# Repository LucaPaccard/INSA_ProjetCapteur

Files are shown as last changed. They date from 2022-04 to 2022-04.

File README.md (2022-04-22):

# 2021-2022_Paccard_Lemaire_Projet_Capteur
Ce projet s'inscrit dans l'UF **"Du capteur au banc de test"** en 4ème année au département de Génie Physique de l'INSA Toulouse.
***
L'objectif de ce dernier est d'élaborer un **capteur de déformation** low-tech à base de graphite. L'application d'une contrainte mécanique sur un capteur en papier sur lequel un dépôt de crayon à papier à été fait, modifie la distance entre les particules de graphite. La conductivité électrique de la couche de graphite est elle aussi modifiée et celà induit une variation de la résistance. C'est cette donnée qui va nous intéresser.

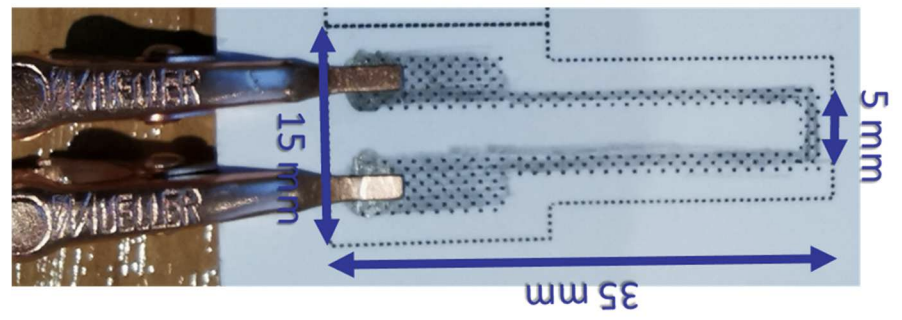
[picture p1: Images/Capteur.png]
<p align="center">

L'ensemble des étapes menées pour réaliser ce capteur, en allant du **design** jusqu'à la **réalisation** en passant par le **codage** seront détaillées dans ce dossier.

## Sommaire
* [1. Description du projet et détail des livrables](#PremiereSection)
* [2. Matériel nécessaire](#DeuxiemeSection)
* [3. Arduino](#TroisiemeSection)
  * [3.1. Librairies utilisées](#TroisiemeSection1)
  * [3.2. Code Arduino](#TroisiemeSection1)
* [4. Application Android](#QuatriemeSection)
* [5. KiCad](#CinquiemeSection)
  * [5.1. Symboles et empreintes des composants](#CinquiemeSection1)
  * [5.2. Schématique](#CinquiemeSection2)
  * [5.3. Placement des composants](#CinquiemeSection3)
  * [5.4. Visualisation 3D](#CinquiemeSection4)
* [6. Fabrication du shield](#SixiemeSection)
  * [6.1. Réalisation du PCB](#SixiemeSection1)
  * [6.2. Perçage et soudure](#SixiemeSection2)
* [7. Simulation](#SeptiemeSection)
* [8. Tests et résultats](#HuigtiemeSection)
  * [8.1. Banc de test](#HuigtiemeSection1)
  * [8.2. Résultats obtenus](#HuigtiemeSection2)
  * [8.3. Analyse des résultats et pistes d'améliorations](#HuigtiemeSection3)
* [9. Datasheet](#NeuviemeSection)
* [Contacts](#DixiemeSection)

## 1. Détail des livrables et description du projet 
Voici l'ensemble des livrables du projet :
- Un **shield PCB** se connectant à une carte **Arduino UNO** contenant un amplificateur transimpédance, un module bluetooth, un écran OLED et un encodeur rotatoire
- Un **code Arduino** permettant de mesurer la déformation du capteur et de piloter le module bluetooth, l'écran OLED et l'encodeur rotatoire
- Une **application Android APK**
- Un **protocole de test** 
- La **datasheet** du capteur de déformation

Tout d'abord, nous avons réalisé un code Arduino permettant de vérifier notre montage contenant un amplificateur transimpédance, un écran OLED, un module bluetooth et un encodeur rotatoire. Une fois le montage fonctionnel, nous avons réalisé le design de notre shield sur le logiciel *KiCad*. Nous l'avons ensuite fabriqué et assemblé (lithographie, perçage, soudage des composants, etc.). En parallèle de cela, nous avons utilisé le logiciel *MIT App Inventor* afin de développer une application Android APK, capable de communiquer et recevoir les informations envoyées par le module bluetooth telles que les valeurs de résistance du capteur mesurées. Nous avons par la suite mis en place un banc de test pour pour caractériser les différents types de capteurs en fonction de leur déformation et de la mine de crayon utilisée (HB, B, 9B, etc.). Enfin, nous avons établi une datasheet à l'aide des résulats obtenus par le banc de test.

## 2. Matériel nécessaire
Pour réaliser le capteur ainsi que le PCB associé, voici la liste des composants nécessaires :
* x2 résistance 100kΩ
* x1 résistance 10kΩ
* x2 résistance 1kΩ
* x1 capacité 1μF
* x3 capacité 100nF
* x1 amplificateur opérationnel LTC1050
* x1 module Bluetooth HC05
* x1 encodeur rotatoire KY_040
* x1 écran OLED I2C 0.91

## 3. Arduino 
### 3.1. Librairies utilisées 
Nous avons utilisé différentes librairies dans notre code Arduino. La librarie ["Adafruit_SSD1306"](/Libraries/Adafruit_SSD1306) permet de contrôller l'écran OLED. La librairie ["Adafruit_BusIO"](/Libraries/Adafruit_busIO) permet de gérer la connexion en I2C et SPI.

### 3.2. Code Arduino 
[Deux codes Arduino](https://github.com/MOSH-Insa-Toulouse/2021-2022_Paccard_Lemaire_Projet_Capteur/tree/main/Arduino) ont été développés sous Arduino IDE pour profiter au mieux des fonctionnalités de notre capteur.

#### Code Graphite_sensor
Le [premier code](https://github.com/MOSH-Insa-Toulouse/2021-2022_Paccard_Lemaire_Projet_Capteur/blob/main/Arduino/Graphite_sensor/Graphite_sensor.ino) permet d'assurer la communication entre la carte Arduino, qui récupère la valeur de tension renvoyée par le capteur, et les différents éléments ajoutés sur le shield soit : l'écran OLED, le module bluetooth et l'encodeur rotatoire. Différents menus sont accessibles sur l'écran OLED :
* Le premier menu permet un simple affichage de la résistance
* Le deuxième menu permet de selectionner le calibre de la résistance affichée sur le menu 1. Cette dernière peut ainsi être affichée en Ω, kΩ ou MΩ.
* Le troisème menu est un chronomètre permettant de savoir le temps d'execution du programme. C'est à dire le temps depuis le programme à été démarré.
* Le quatrième menu permet l'affichage d'une image.

En parallèle, le module bluetooth envoie les données de tension et de résistance à une application mobile qui sera détaillée dans la partie suivante.

#### Code Angle_calibration
Le [second code](https://github.com/MOSH-Insa-Toulouse/2021-2022_Paccard_Lemaire_Projet_Capteur/blob/main/Arduino/Angle_calibration/Angle_calibration.ino) Arduino permet d'effectuer un calcul d'angle par rapport à la calibration du capteur. L'utilisateur rentre les valeurs de la résistance à plat et à la position la plus courbée possible en appuyant sur le bouton poussoir présent sur l'encodeur rotatoire. En considérant la variation de résistance linéaire, un produit en croix est ensuite fait pour asssocier une valeur de résistance à un angle de déformation.

## 4. Application Android 

Nous avons réalisé une [application Android](https://github.com/MOSH-Insa-Toulouse/2021-2022_Paccard_Lemaire_Projet_Capteur/tree/main/Application%20bluetooth) grâce au site *MIT App Inventor* afin d'instaurer une communication entre notre module bluetooth HC-05 et un smartphone Android. Cette application possède différentes fonctionnalités : après avoir choisi dans un menu l'appareil auquel on souhaite se connecter, et que la connexion a été effectuée, différentes informations sont affichées sur l'écran du téléphone. En premier, on trouve la tension VADC en volts de sortie du circuit, elle est envoyée sous forme d'un byte à l'application depuis la carte Arduino, puis elle est reconvertie dans le code de l'application en float permettant d'afficher les décimales. C'est ensuite la valeur de la résistance du capteur en graphite qui est affichée en Méga Ohms, la valeur est directement calculée depuis l'application à partir de la valeur de VADC reconvertie en float. Finalement, la variation de la valeur de résistance est tracée en fonction du temps dans un graphique (canva) au-dessous. Nous avons enregistré un graphique avec uniquement des axes et leurs titres sous forme d'image que nous avons ensuite mis en fond du graphique pour le tracé. 

## 5. KiCad 
### 5.1. Symboles et empreintes des composants 
* Amplificateur LTC1050

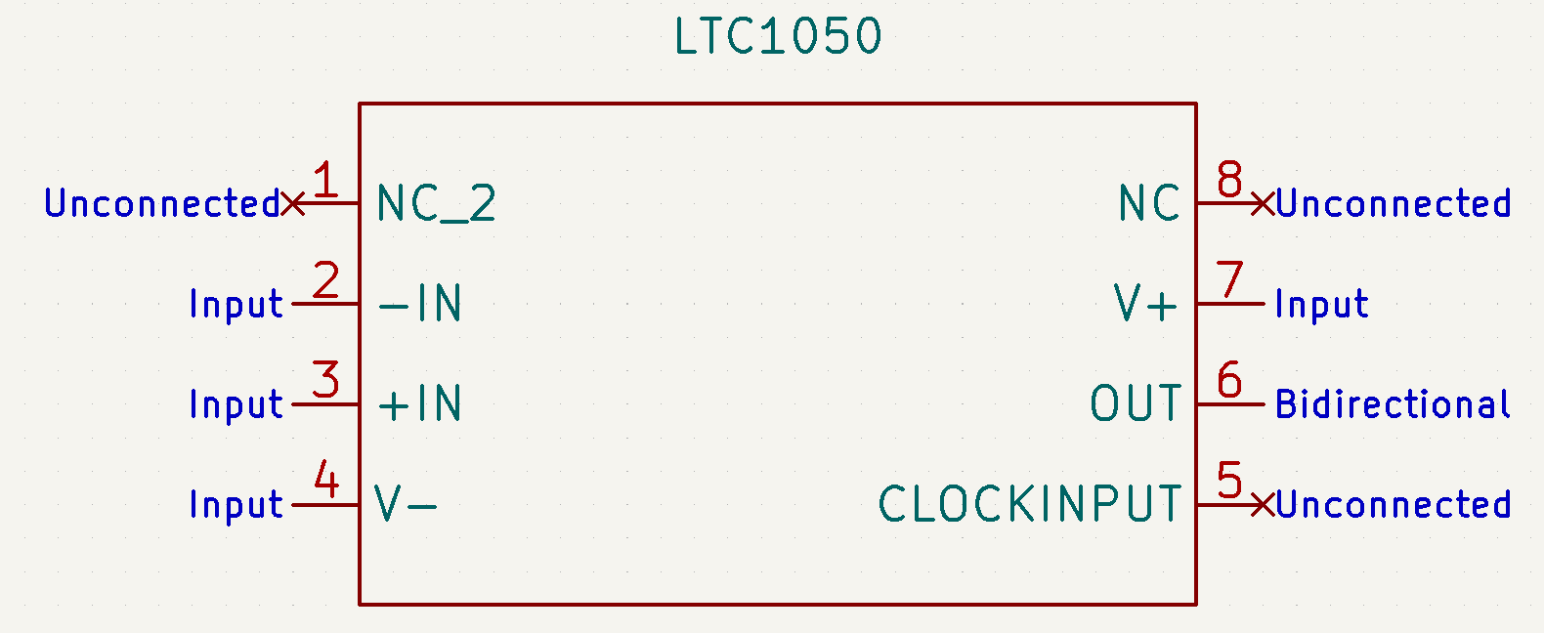
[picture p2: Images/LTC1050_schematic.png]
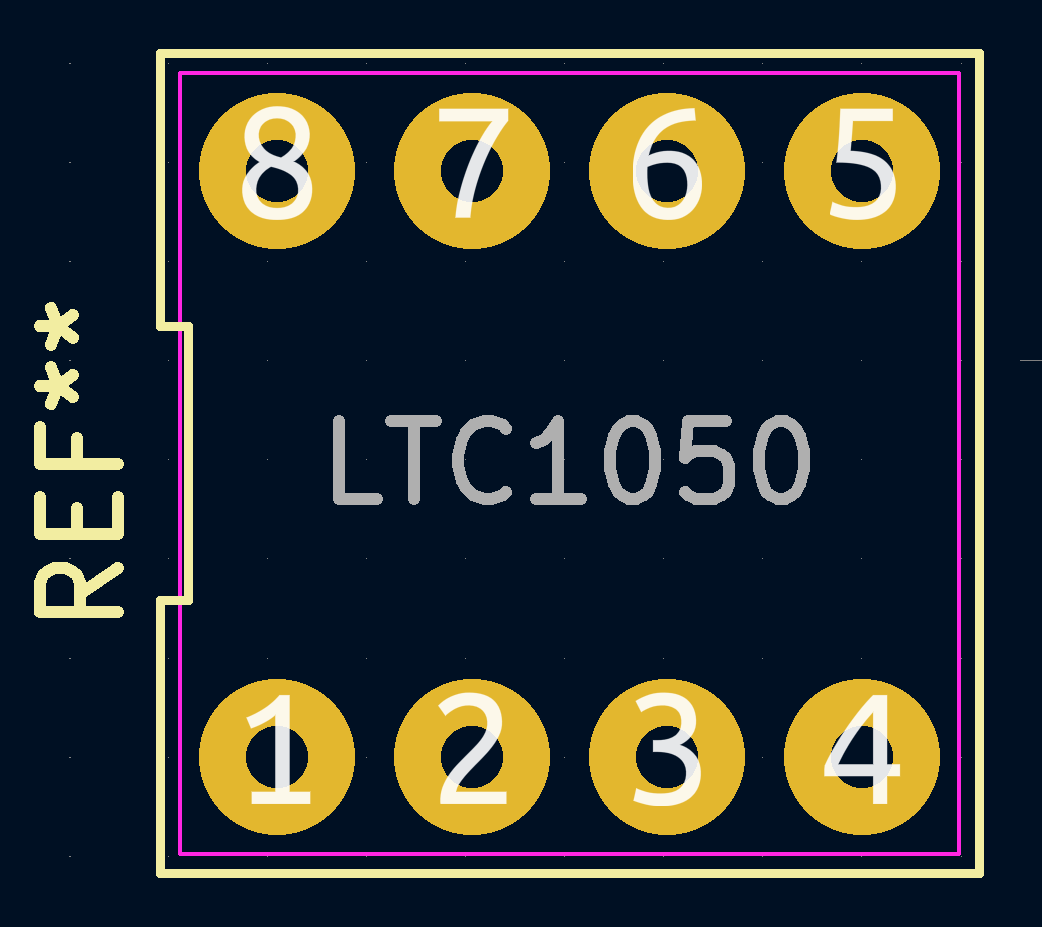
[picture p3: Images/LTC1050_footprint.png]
 

* Ecran OLED

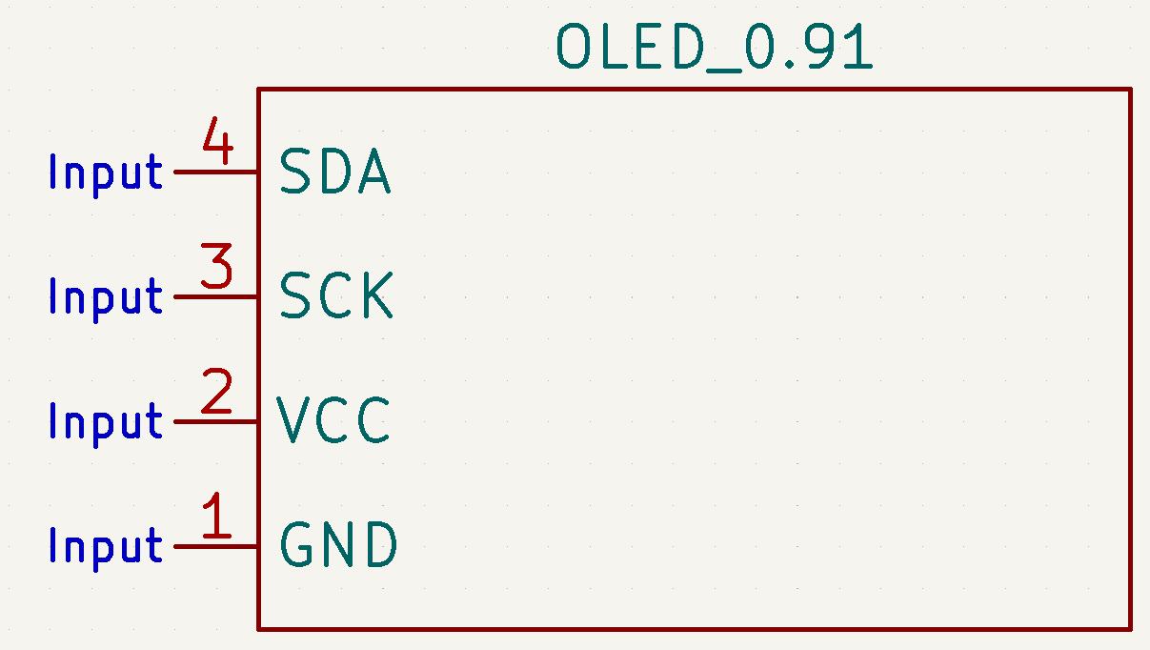
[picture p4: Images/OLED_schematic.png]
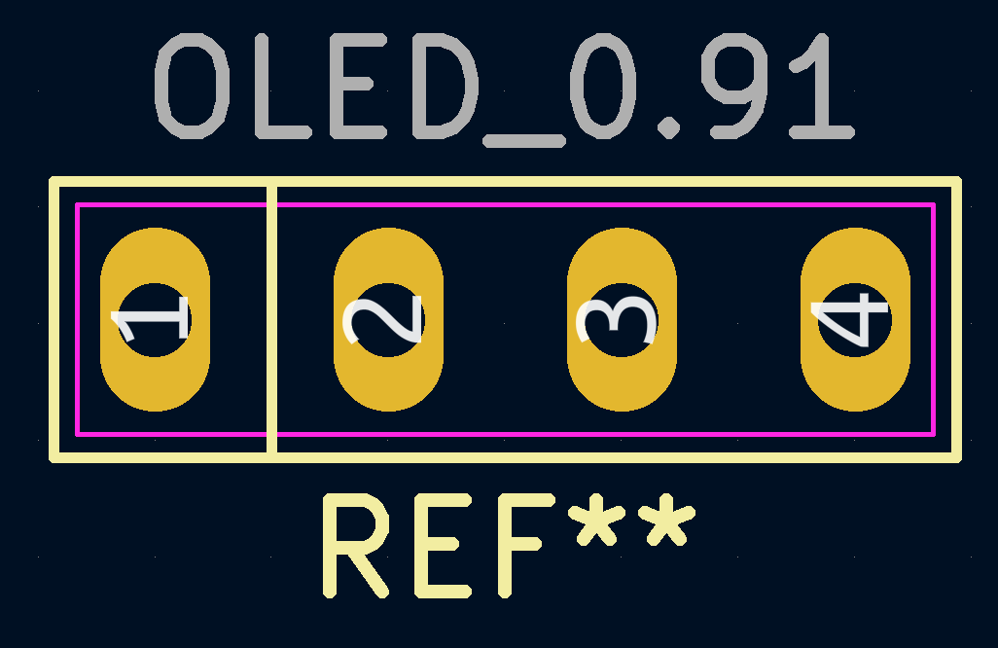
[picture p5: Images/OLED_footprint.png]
 

* Encodeur rotatoire KY_040

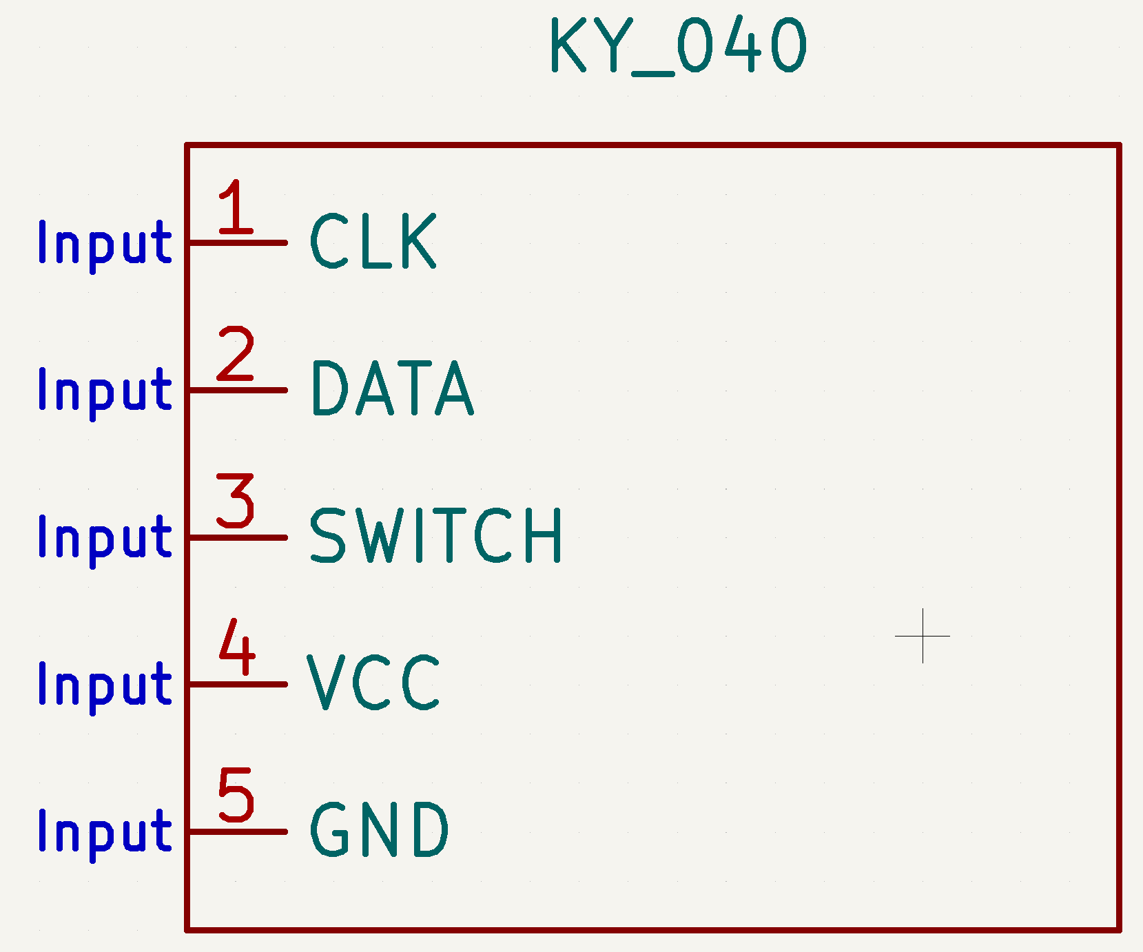
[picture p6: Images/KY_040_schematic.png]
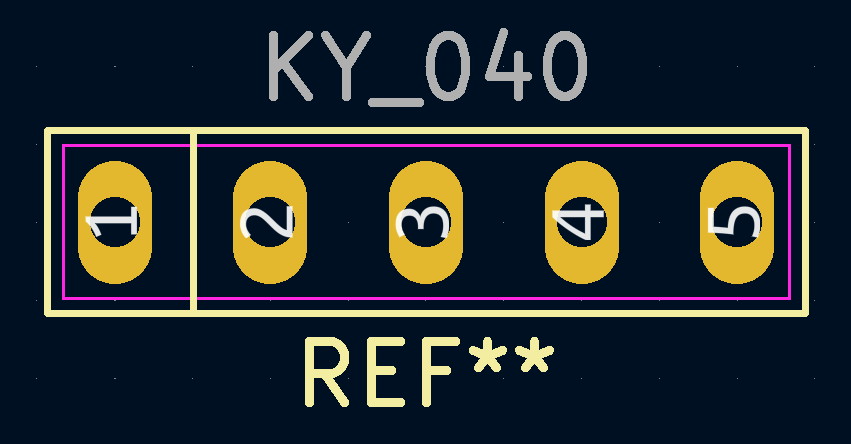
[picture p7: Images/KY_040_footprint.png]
 

* Module bluetooth HC05

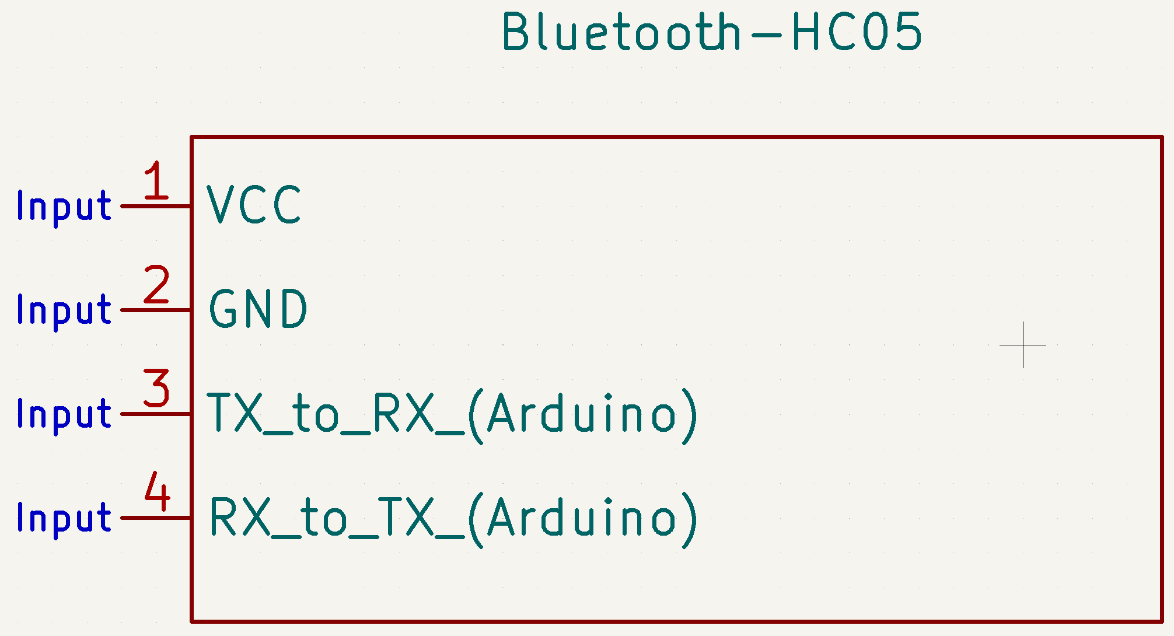
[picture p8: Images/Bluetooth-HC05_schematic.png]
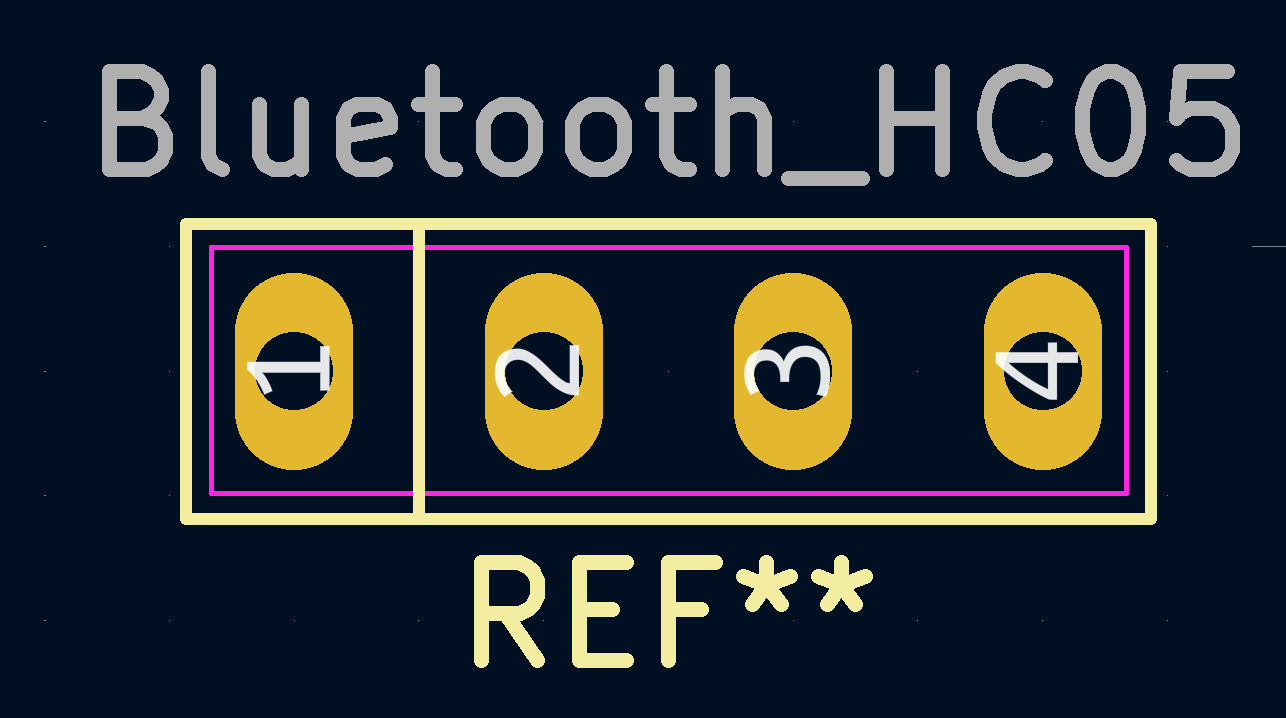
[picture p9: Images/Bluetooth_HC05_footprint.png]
 

### 5.2. Schématique 
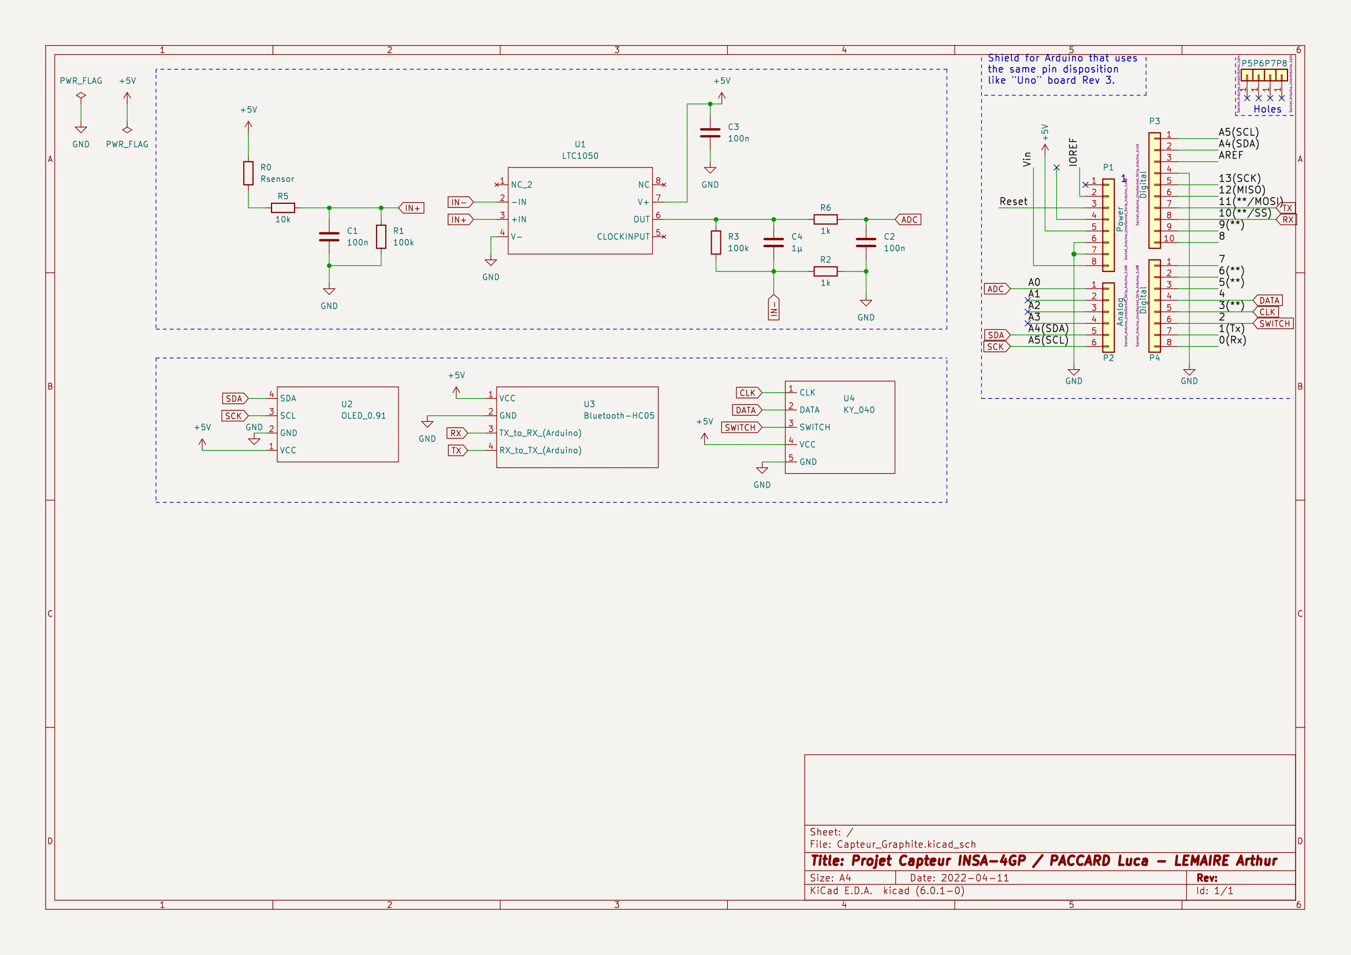
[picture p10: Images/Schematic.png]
<p align="center">

Une fois les empreintes créées, nous avons réalisé le schéma de notre shield. En haut à droite sont représentées les broches de la carte Arduino. En haut au milieu est représenté l'amplificateur transimpédance et en bas du schématique se trouvent l'écran OLED, le module bluetooth et l'encodeur rotatoire.

### 5.3. Placement des composants 
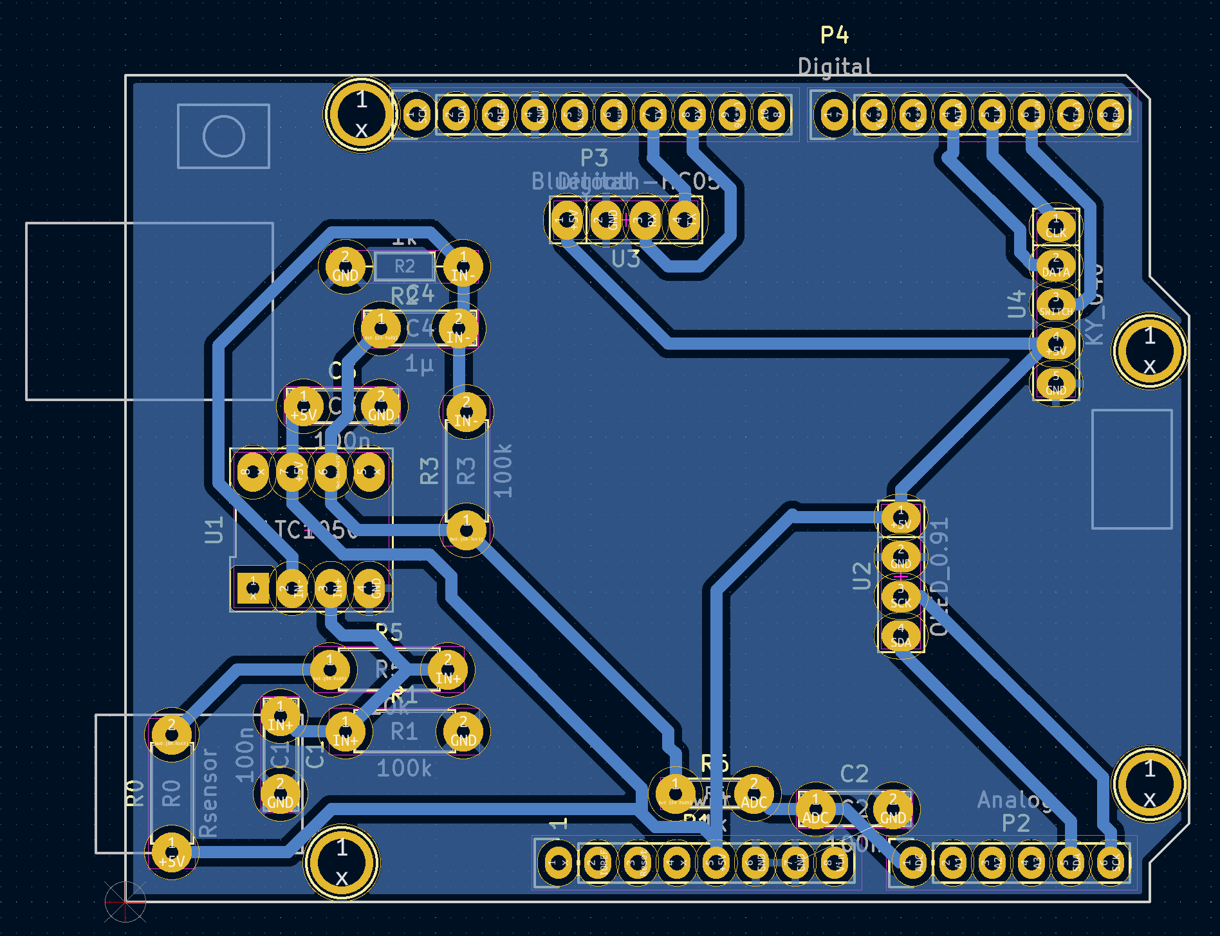
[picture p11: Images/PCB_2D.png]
<p align="center">

### 5.4. Visualisation 3D 
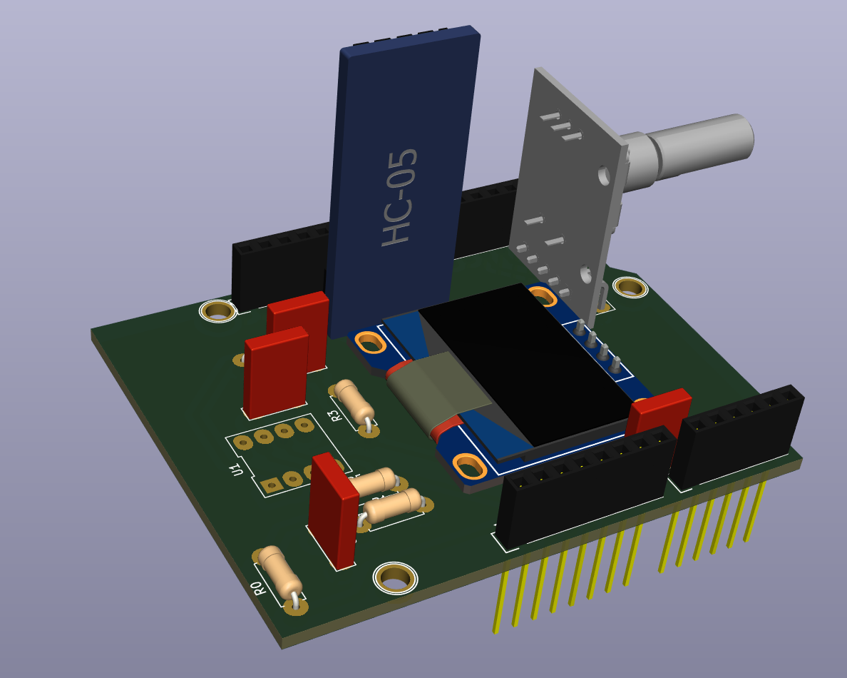
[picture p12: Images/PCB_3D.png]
<p align="center">

## 6. Fabrication du shield 
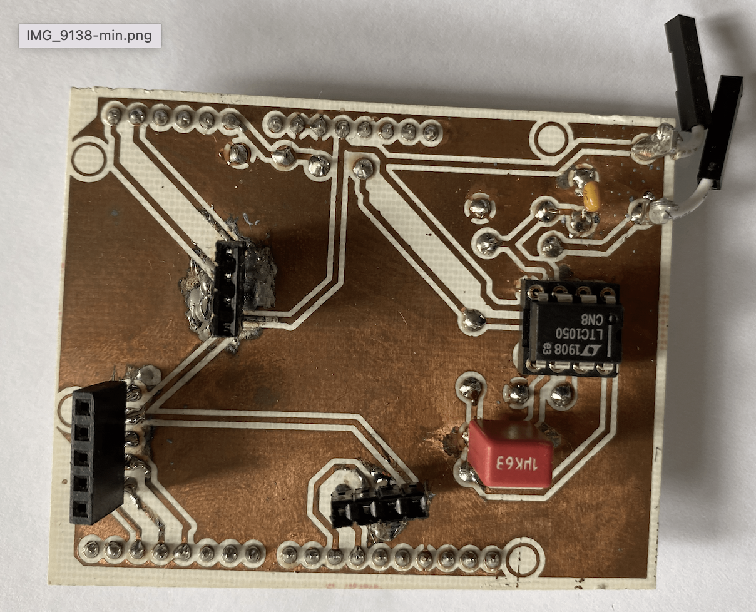
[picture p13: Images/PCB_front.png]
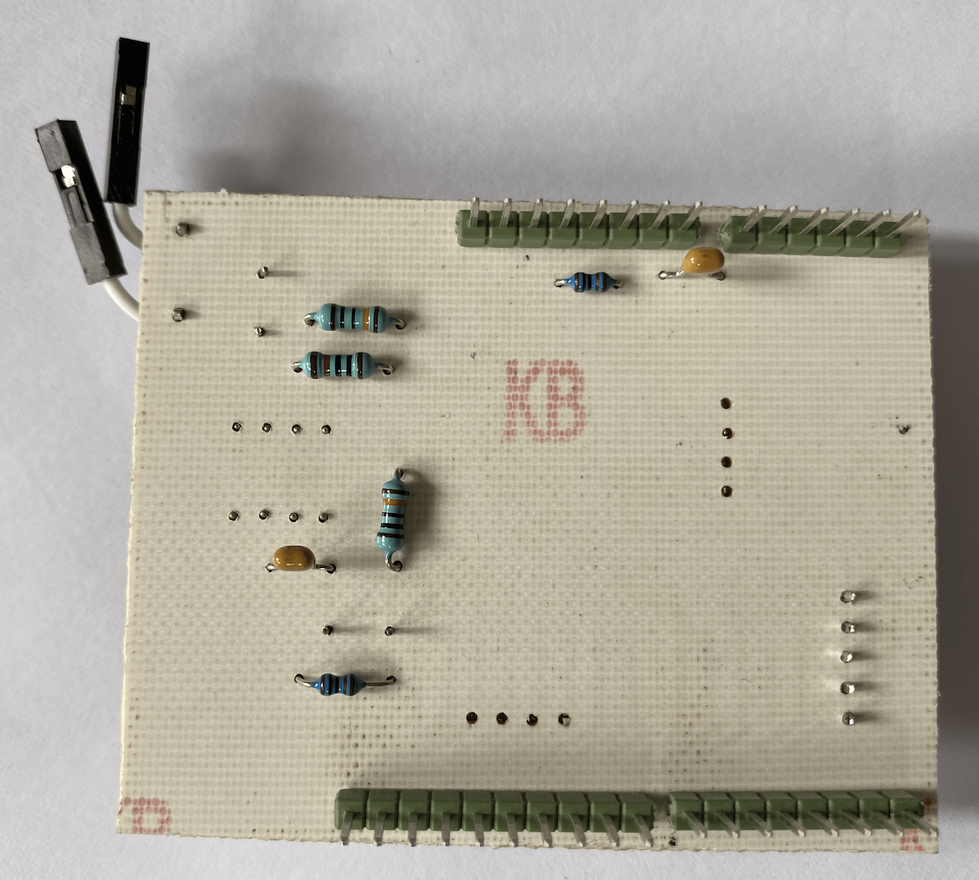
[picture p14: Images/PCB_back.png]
 

### 6.1. Réalisation du PCB  
Le PCB a été réalisé au sein des départements de Génie Physique (GP) et Génie Électrique et Informatique (GEI) de l'INSA Toulouse avec l'aide de Catherine Crouzet. Notre PCB à été fabriqué à partir d'une plaquette d'epoxy recouverte d'une fine couche de cuivre (environ 60μm). 
Nous avons imprimé sur du papier calque la modélisation de notre PCB effectuée sur le logiciel *KICAD* pour ensuite insoler aux UV notre plaquette avec la silouhette par-dessus pendant quelques minutes. À l'aide d'un révelateur, nous avons retiré la partie de la résine non insolée.
La plaquette d'expoxy est ensuite placée dans un bain de perchlorure de fer pour la gravure, opération durant 7 minutes. Le cuivre non protégé par la résine est ainsi retiré de la plaquette ce qui nous permet d'obtenir le PCB avec les pistes souhaitées.
Enfin, de l'acétone est appliquée sur la plaquette pour éliminer les dernières traces de résine.

### 6.2. Perçage et soudure  
Nous avons ensuite percé notre PCB aux endroits où les différents composants seront insérés à l'aide d'une perceuse électrique. Le diamètre des trous dépend des différents composants à placer :
* ⌀ 0.8mm : AOP LTC1050, résistances et capacités
* ⌀ 1.0mm : Broches de connexion de la carte Arduino Uno et headers des différents modules (OLED, bluetooth, encodeur rotatoire)
* ⌀ 1.2mm : Broches de connexion du capteur de déformation

Notre PCB ayant été imprimé en face avant, certains composants ont été placé en face avant et d'autres en face arrière pour faciliter la soudure et la connexion à la carte Arduino Uno.

## 7. Simulation  
Nous avons simulé notre amplificateur transimpédance sur le logiciel *LTSpice* afin de savoir le comportement que notre circuit aura une fois branché à de réelles valeurs de tension. Les différentes simulations réalisées sur le logiciel nous ont permis d'une part de vérifier le bon fonctionnement du circuit et de chacun des composants intégrés, et d'autre part de comprendre l'utilité de chacun. Le détail de la démarche suivie et des résultats obtenus est disponible dans le document [Simulation_LTspice](https://github.com/MOSH-Insa-Toulouse/2021-2022_Paccard_Lemaire_Projet_Capteur/blob/main/Simulation_LTspice.pdf).

## 8. Tests et résultats  
### 8.1. Banc de test  
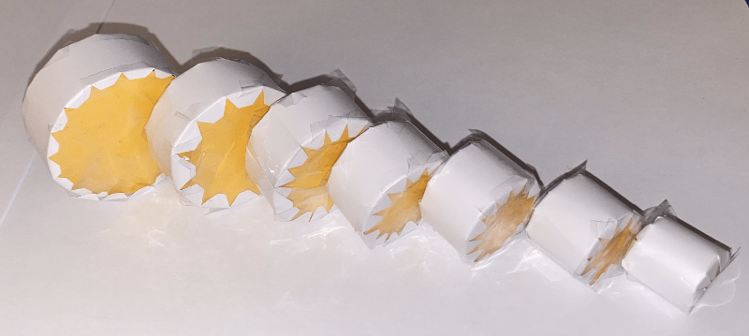
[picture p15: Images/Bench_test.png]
<p align="center">

Nous avons testé notre capteur sur un banc de test que nous avons conçu à partir de feuilles de papier épais. Nous avons fabriqué 7 cylindres de diamètre variable, allant de 5cm à 2cm par pas de 0,5cm.
En enrobant les différents cylindres avec notre capteur, nous appliquons une déformation maitrisée que nous pouvons calculer avec la formule : 
*ε = e / (2•R)*, avec ε la déformation, e l'épaisseur de notre capteur, et R le rayon de courbure appliqué soit le rayon de nos cylindres.

Nous avons décidé de réaliser des mesures de compression (graphite vers le cylindre) du capteur et pas en tension (graphite vers l'extérieur), car bien que ces deux méthodes soient possibles, les valeurs de  résistance renvoyées par notre capteur en tension n'étaient pas exploitables.

### 8.2. Résultats obtenus  
Les résultats complets de notre banc de test sont disponibles dans le dossier [Results](https://github.com/MOSH-Insa-Toulouse/2021-2022_Paccard_Lemaire_Projet_Capteur/tree/main/Results). 

### 8.3. Analyse des résultats et pistes d'améliorations  
En comprimant notre capteur, les particules de graphite se rapprochent les unes des autres, ce qui facilite la conduction dans le réseau percolé du système. De la même manière, en mettant notre capteur en tension, certains chemins de percolation se retrouvent brisés ce qui augmente la résistance du capteur.
En fonction du type de crayon utilisé, les variations relatives de résistance changent. En effet, plus le crayon est gras, c'est à dire qu'il dépose plus de graphite, moins sa variation relative de résistance est élevée. Cette caractéristique se vérifie sur nos [résultats](https://github.com/MOSH-Insa-Toulouse/2021-2022_Paccard_Lemaire_Projet_Capteur/tree/main/Results) et dans notre [datasheet](https://github.com/MOSH-Insa-Toulouse/2021-2022_Paccard_Lemaire_Projet_Capteur/blob/main/datasheet.pdf).
 
#### Comparaison avec le Flex-Sensor SEN-10264

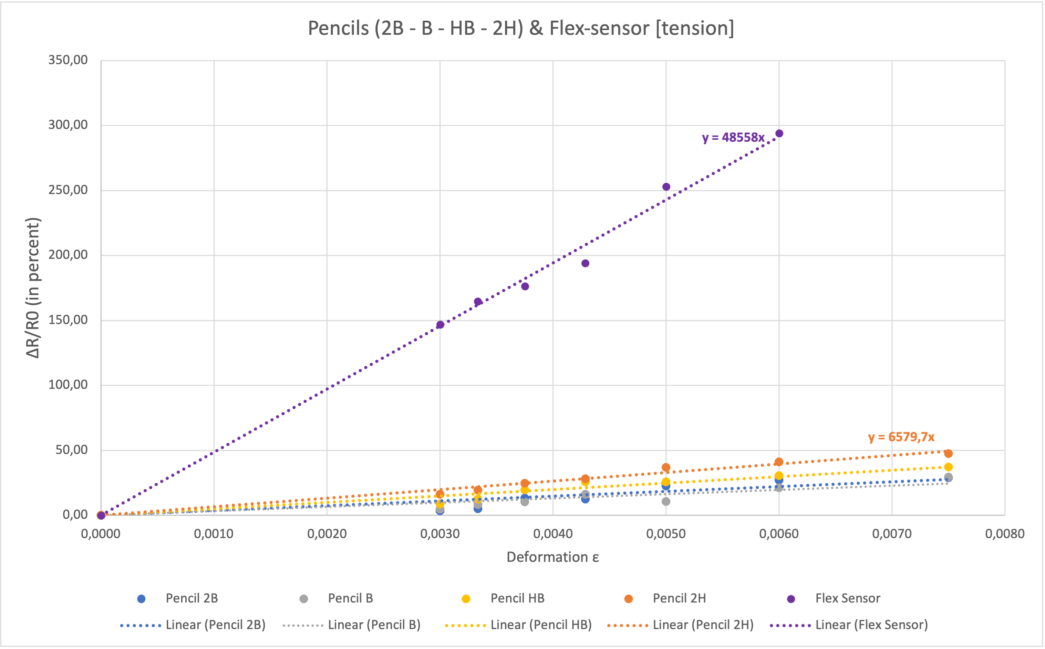
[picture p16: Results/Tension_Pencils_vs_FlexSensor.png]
 <p align="center">  
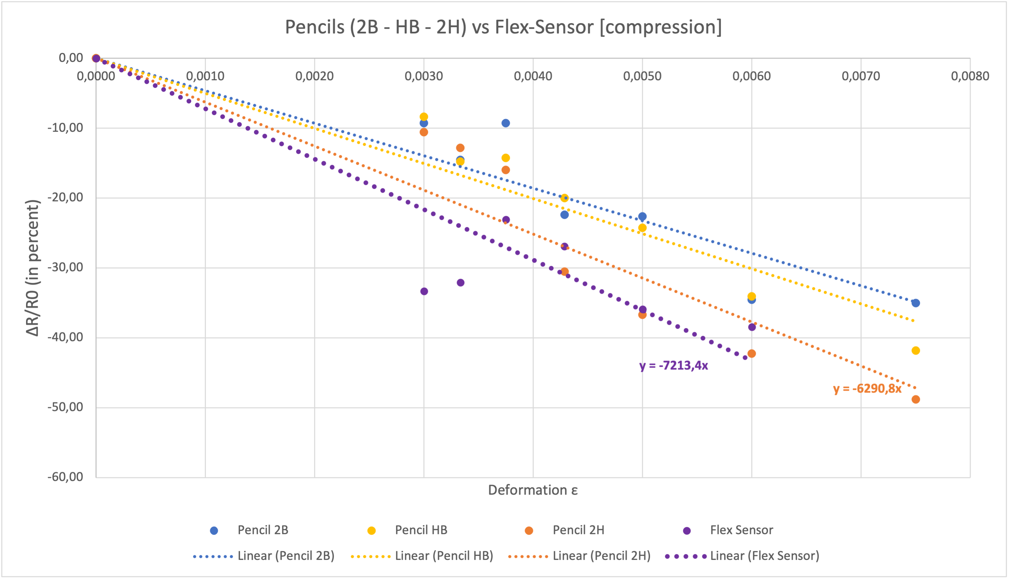
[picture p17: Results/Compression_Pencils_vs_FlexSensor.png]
 <p align="center">
 
Nous avons étudié la réponse en résistance du flex-sensor SEN-10264 pour le comparer à nos capteurs low-tech à base de graphite. Nous avons observé que le flex-sensor industriel est plus sensible à la déformation (i.e. ΔR/R0 augmente plus rapidement avec la déformation) que nos capteurs de graphite lorsque l'on applique une déformation en tension. Cependant, en compression, le flex-sensor SEN-10264 possède une sensibilité du même ordre de grandeur que nos différents capteurs.
 
#### Pistes d'améliorations 
Certains point peuvent être améliorés dans notre projet :
* Le dépot de graphite sur le capteur est difficile à maîtriser et il est ainsi difficile de fabriquer plusieurs capteurs identiques
* Notre banc de test fourni des résultats répétables, il pourrait cependant être envisageable de fabriquer ce même banc de test en impression 3D pour augmenter sa résistance et longévitée.
* Sur notre PCB, l'ajout d'un potentiomètre digital permettrait de pouvoir travailler sur une gamme de résistance plus grande car ce dernier modulera la valeur de tension de sortie en fonction de la résistance du capteur

## 9. Datasheet  
La datasheet de notre capteur est disponible [ici](https://github.com/MOSH-Insa-Toulouse/2021-2022_Paccard_Lemaire_Projet_Capteur/blob/main/datasheet.pdf).

## Contacts  
Pour toutes questions relatives aux différentes parties du projet, que ce soit du KiCad au code Arduino, n'hésitez pas à nous contacter !
* Luca Paccard : paccard@insa-toulouse.fr
* Arthur Lemaire : a_lemair@insa-toulouse.fr

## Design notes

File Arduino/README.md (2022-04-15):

# Codes Arduino

Deux codes ont été développés pour proffiter au mieux des fonctionnalités de notre capteur.

## Sommaire

* [Graphite_sensor](#PremiereSection)
* [Angle_calibration](#DeuxiemeSection)

## Graphite_sensor 
Ce [premier code Arduino](https://github.com/MOSH-Insa-Toulouse/2021-2022_Paccard_Lemaire_Projet_Capteur/blob/main/Arduino/Angle_calibration/Angle_calibration.ino) permet d'afficher un menu contenant quatre sous-menus.
* Le premier sous-menu permet d'afficher en direct la valeur de résistance du capteur et la tension lue par la carte Arduino.
* Le deuxième sous-menu permet de choisir un calibre pour l'affichage de la résistance dans le premier menu. Les calibres disponibles sont : Ω, kΩ et MΩ.
* Le troisème sous-menu permet d'afficher la durée d'execution du programme.
* Le dernier sous-menu permet d'afficher une image.

## Angle_calibration 
Ce [second code Arduino](https://github.com/MOSH-Insa-Toulouse/2021-2022_Paccard_Lemaire_Projet_Capteur/blob/main/Arduino/Graphite_sensor/Graphite_sensor.ino) permet d'effectuer un calcul d'angle par rapport à la calibration du capteur. 
L'utilisateur rentre les valeurs de la résistance à plat et à la position la plus courbée possible. En considérant la variation de résistance linéaire, un produit en croix est ensuite fait pour asssocier une valeur de résistance à un angle de déformation.

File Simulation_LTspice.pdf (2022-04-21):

## Simulation du fonctionnement du circuit sous LTspice

Introduction :

Durant ce projet, nous avons fabriqué un capteur en graphite, et pour récupérer la valeur de sa résistance et nous avons élaboré un circuit électronique autour, contenant un amplificateur transimpédance. L’utilité de cet amplificateur s’explique par la valeur très faible de tension étant récupérée à la sortie du capteur. En effet, la résistance de celui-ci se trouvant aux alentours de 50M Ohms, et la tension d’alimentation étant de 5 Volts, le courant en sortie du capteur est d’environ 100nA. Ainsi, il est trop faible pour être capté par la carte Arduino et il nous faut donc amplifier ce courant, avec les risques que cela comporte. Dans ce document, nous allons voir ce qui a été mis en place pour une utilisation optimale de l’amplificateur et pour éviter les éventuels problèmes liés à son utilisation. De plus, dans l’élaboration de circuit ou d’autre objets, il est important d’utiliser les puissants outils de simulation disponibles afin de vérifier le fonctionnement et les paramètres avant la construction, cela permet d’éviter de nombreux problèmes par la suite.

Simulation du circuit :

Nous commençons par vérifier la fonctionnalité dans les conditions nominales, et pour ce faire, nous avons fait une simulation transient (.tran) d’une durée de 12 secondes, qui a fait fonctionner le circuit de manière normale, selon les composants présents. De cette manière, nous pouvons vérifier que le signal est bel et bien amplifié en sortie de montage (VADC) jusqu’à une valeur mesurable pour la carte Arduino, et c’est bien ce que l’on voit sur le graphique puisque la tension de sortie de montage monte à 1 Volt. Le circuit fonctionne donc bien dans les conditions nominales.

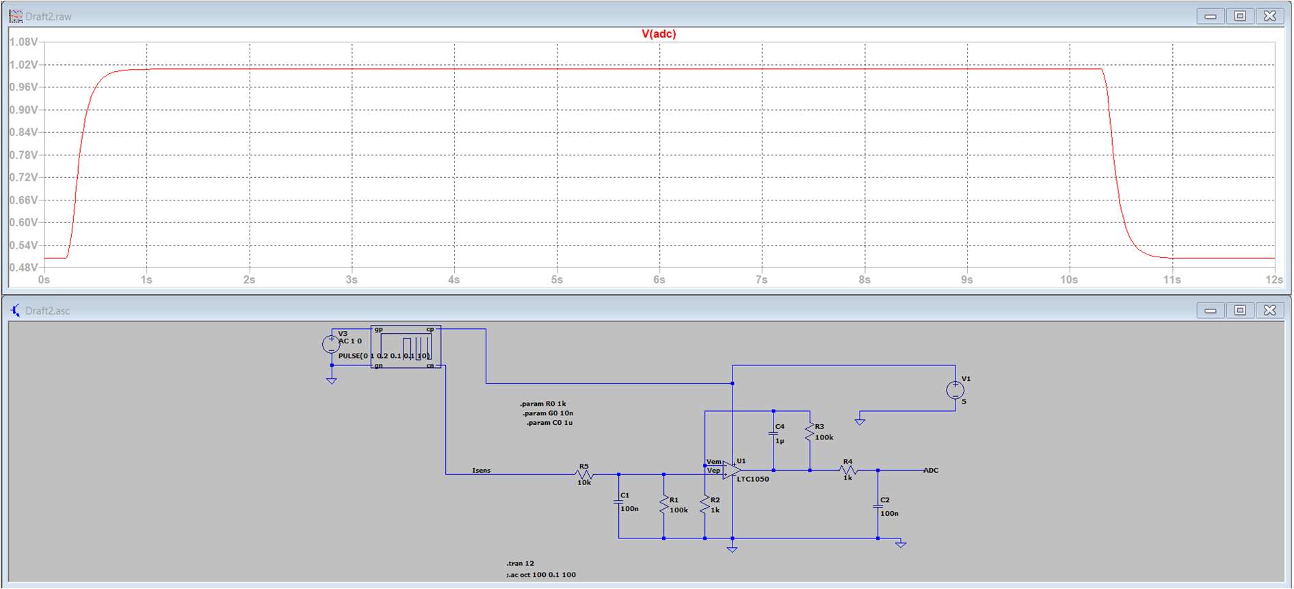
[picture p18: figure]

Simulation du fonctionnement du circuit dans les conditions nominales

Puisque nous incluons dans notre circuit un amplificateur transimpédance, il nous faut vérifier que ses caractéristiques intrinsèques ne risquent pas de fausser nos mesures, et vérifier qu’il convient pour le circuit. Nous allons commencer par nous intéresser à l’incidence de la tension d’offset de l’amplificateur, puis nous nous intéresserons à l’incidence du courant d’offset.

La datasheet de l’amplificateur transimpédance nous permet de récupérer deux informations essentielles pour répondre à cette première interrogation : le maximum offset voltage qui est de 5µV, et le maximum offset voltage drift qui est de 0.05µV/°C, à 20°C on a donc 0.1µv d’offset. Il faut comparer ces valeurs avec la valeur de tension mesurée.

On peut facilement calculer le gain de l’étage de l’amplificateur à partir du schéma du circuit : (R2+R3)/R2=(1k+500k)/1k=501. Les caractéristiques de notre circuit nous imposent de choisir un amplificateur avec un faible courant d’entrée, et un encore plus faible offset de tension. De plus, comme le courant Isens est d’environ 100nA, on a alors une tension mesurée d’environ 10mV. En effet, comme la résistance R3 vaut 100kOhms, on a alors U = R*I = 100k * 100E
-9 = 10 mV. On a
alors, avec le gain de l’étage amplificateur, une tension d’environ 5V au niveau de l’ADC (501*10E -3
= 5V).

On peut donc faire la comparaison entre les deux valeurs : 10mV >> 5µV. Cette valeur est donc bien supérieure à celle de l’offset de l’amplificateur, et l’incidence est donc négligeable, soit acceptable. On mentionnera toutefois que le drift est lui aussi amplifié par l’amplificateur, et il faut donc prendre garde à ce que cela ne devienne pas un problème, même si ce n’est pas le cas ici.

En ce qui concerne le courant d’offset, on suit un raisonnement a peu près similaire à précédemment. D’après la datasheet de l’amplificateur LTC1050C, le courant d’entrée maximum est de ± 200pA, et le courant mesuré dans le circuit est d’environ 100nA comme nous l’avons vu précédemment. Ainsi, la valeur du courant d’entrée maximum est très inférieure (10E
-3) à la valeur
mesurée de courant, et elle est donc négligeable, on peut donc considérer que son incidence est acceptable.

Il nous faut maintenant nous intéresser aux bruits et à leurs filtrages. En effet, plusieurs sources de bruits sont présentes et risquent de polluer notre signal de sortie, il nous a donc fallu les filtrées grâce à trois étages de filtre passe-bas, que nous allons analyser ici. Nous préciserons le bruit qu’ils filtrent et leur fréquence de coupure.

Nous avons introduit trois filtres passe-bas dans le circuit, chacun étant destiné à atténuer le bruit d’une source, nous allons ici les expliciter, en précisant de quelle source provient le bruit qu’ils diminuent, et leur fréquence de coupure respective. Leur fréquence de coupure est mesurée lorsqu’on constate une chute de 3dB par rapport au bruit originel qui se situe aux alentours de 140dB. Nous avons réalisé des simulations (.ac) afin d’accéder au diagramme de Bode de la sortie, modifiée en fonction du filtre passe-bas utilisé, en ne laissant actif seul l’étage de filtre nous intéressant à chaque fois, afin de trouver les fréquences de coupures de chaque étage.

Le premier filtre passe-bas se situe au niveau de l’entrée inverse de l’amplificateur. Il permet de réduire le bruit dû à l’alimentation 5V du circuit. Sa fréquence de coupure se situe à environ 1.6Hz.

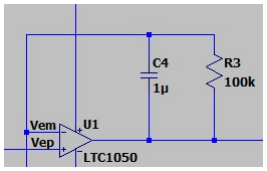
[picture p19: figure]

Schéma du premier étage de filtre passe-bas dans le circuit (réalisé sur LTSpice).

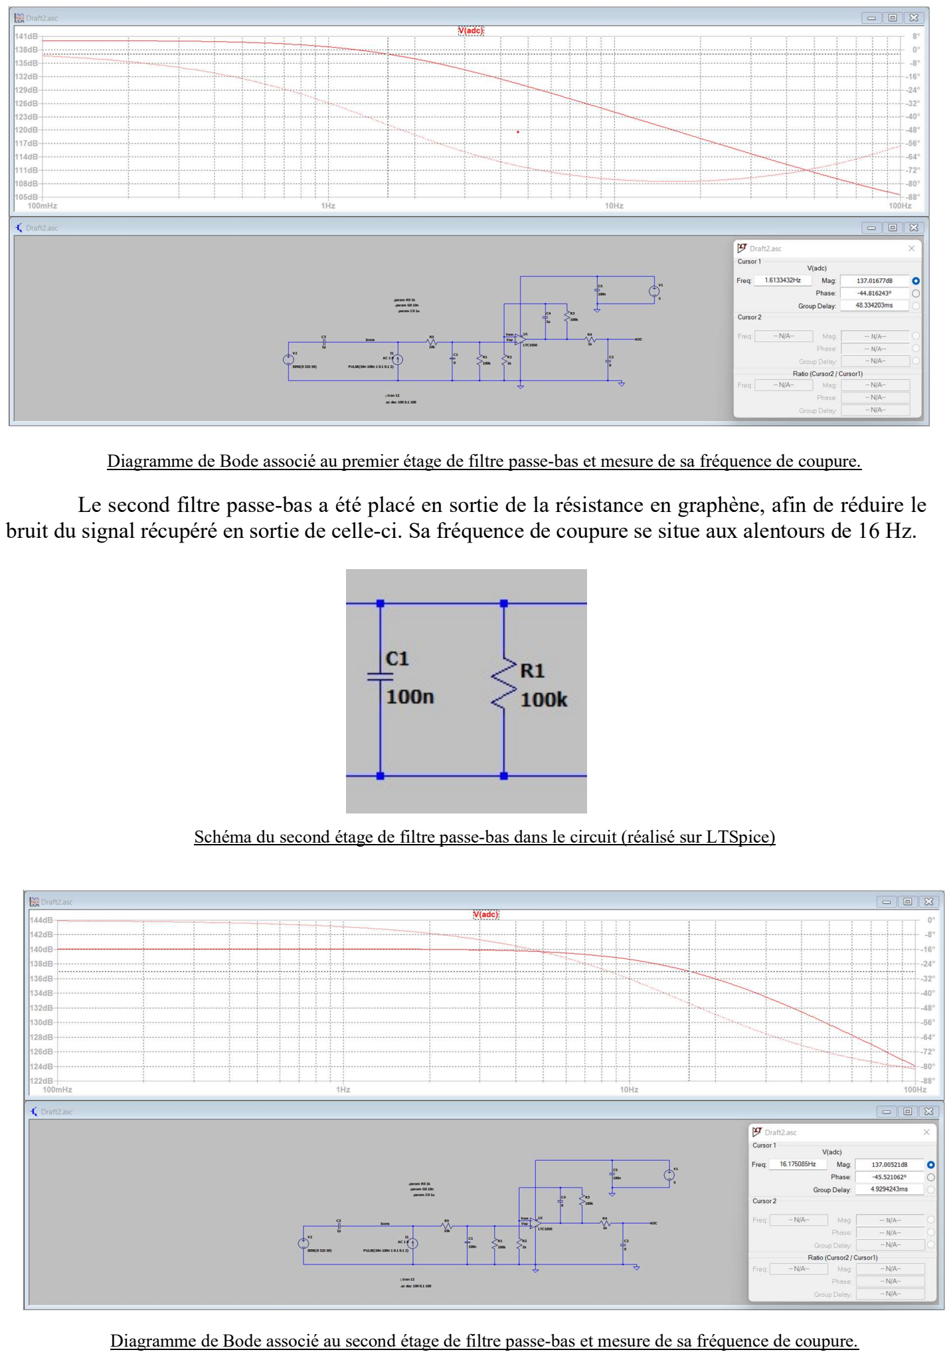
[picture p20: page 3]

Diagramme de Bode associé au premier étage de filtre passe-bas et mesure de sa fréquence de coupure.
Le second filtre passe-bas a été placé en sortie de la résistance en graphène, afin de réduire le bruit du signal récupéré en sortie de celle-ci. Sa fréquence de coupure se situe aux alentours de 16 Hz.

Schéma du second étage de filtre passe-bas dans le circuit (réalisé sur LTSpice)

Diagramme de Bode associé au second étage de filtre passe-bas et mesure de sa fréquence de coupure.

Enfin, le troisième filtre passe-bas se situe en sortie de l’amplificateur opérationnel, afin de récupérer un signal le plus clair possible pour la mesure de VADC. Sa fréquence de coupure se situe à environ 1.6kHz.

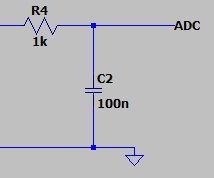
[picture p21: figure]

Schéma du troisième étage de filtre passe-bas dans le circuit (réalisé sur LTSpice)

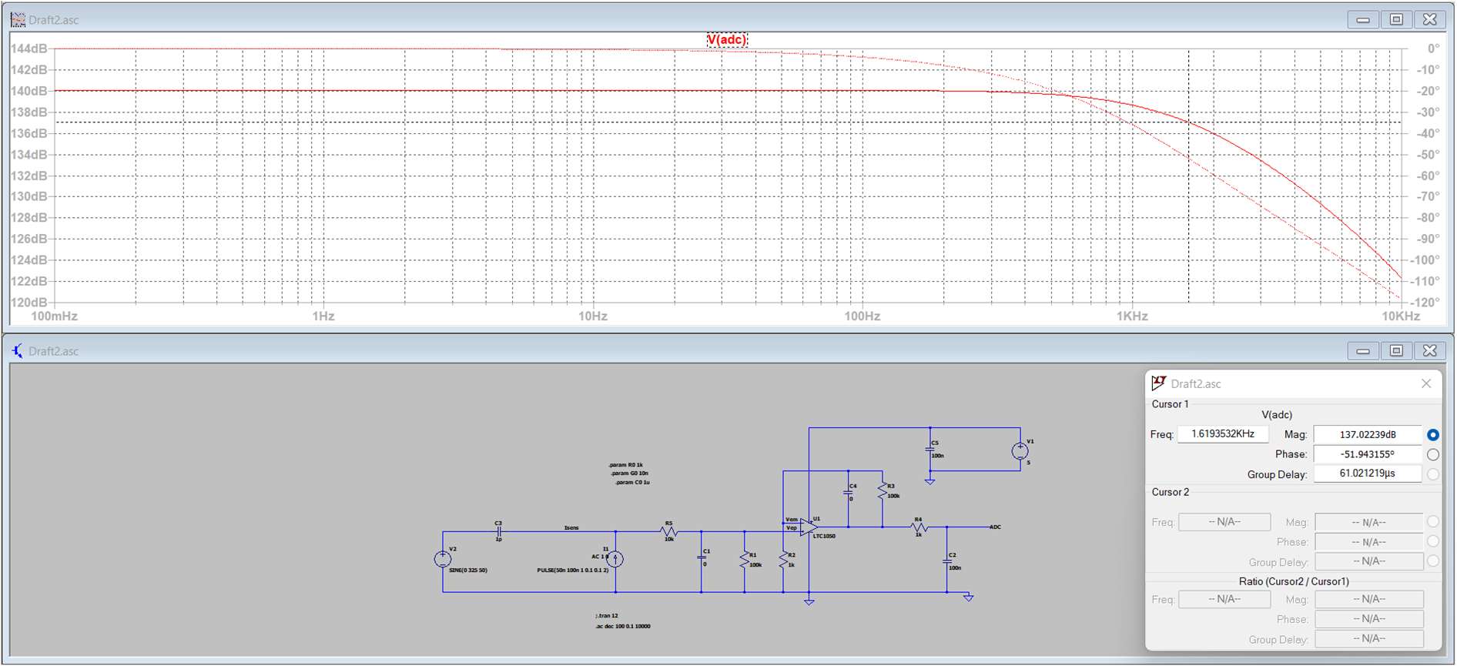
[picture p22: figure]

Diagramme de Bode associé au troisième étage de filtre passe-bas et mesure de sa fréquence de coupure.

Puisque nous avons mis en place des filtrages de bruit, il serait intéressant de vérifier leur efficacité, et nous allons donc vérifier ici le filtrage d’un bruit en courant de 50Hz, et le filtrage d’un bruit à la fréquence limite de repliement.

Comme précisé auparavant, nous avons ajouté dans le circuit trois étages de filtre passe-bas afin de contrecarrer les effets des différents bruits pouvant affecter le circuit. Ici, nous allons voir l’atténuation du bruit en courant de 50Hz dû au couplage capacitif avec le réseau 230V.

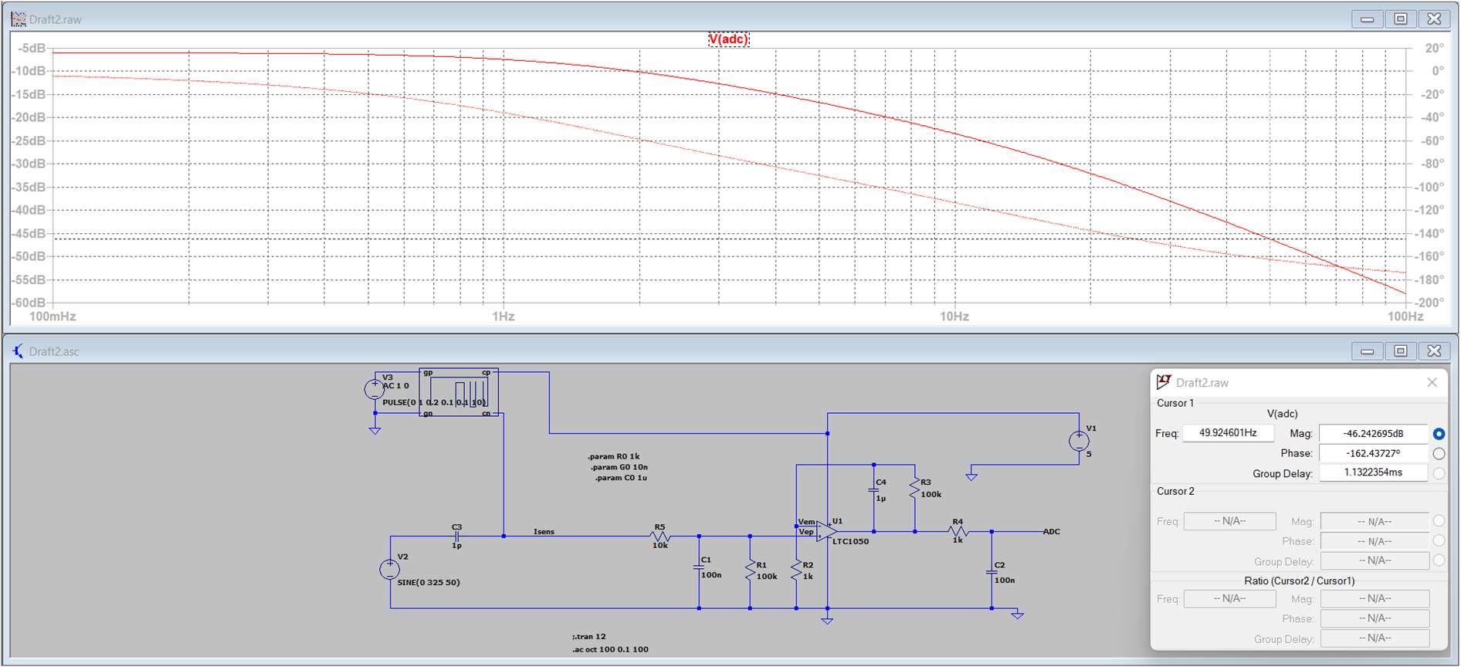
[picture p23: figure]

Diagramme de Bode du circuit avec tous les filtres pour calcul de l’atténuation d’un bruit en courant de 50Hz.

On réalise donc une simulation en courant alternatif (.ac) sur le circuit dans lequel nous avons incorporé un bruit à la fréquence de 50Hz afin d’avoir accès au diagramme de Bode de la sortie, ce qui nous permettra de retrouver l’atténuation. Comme on peut le voir ici, à 50 Hz, nous sommes a -46dB, et comme le diagramme débute à -7dB, nous avons donc une atténuation globale de 39dB pour un bruit en courant de 50 Hz. Le filtrage est donc efficient et il était utile de mettre en place cet étage de filtre passe-bas.

Dans le cas de la carte de l’Arduino Uno, la plus grande fréquence d’échantillonnage utilisable sans perte de qualité est de 15.4kHz. Nous avons intérêt à faire fonctionner l’ADC à cette fréquence car elle permet de faciliter le filtrage anti-repliement (dernier étage de filtre passe-bas). La fréquence limite de repliement, ou fréquence de Nyquist, est la fréquence maximale que doit contenir un signal pour permettre sa description non ambiguë (donc sans perte de qualité) par un échantillonnage à intervalles réguliers, et elle est égale à la moitié de la fréquence d'échantillonnage. On a donc une fréquence limite de repliement égale à 7.7 kHz, et nous allons simuler un bruit à cette fréquence pour déterminer l’atténuation globale d’un bruit un courant à la fréquence limite de repliement.

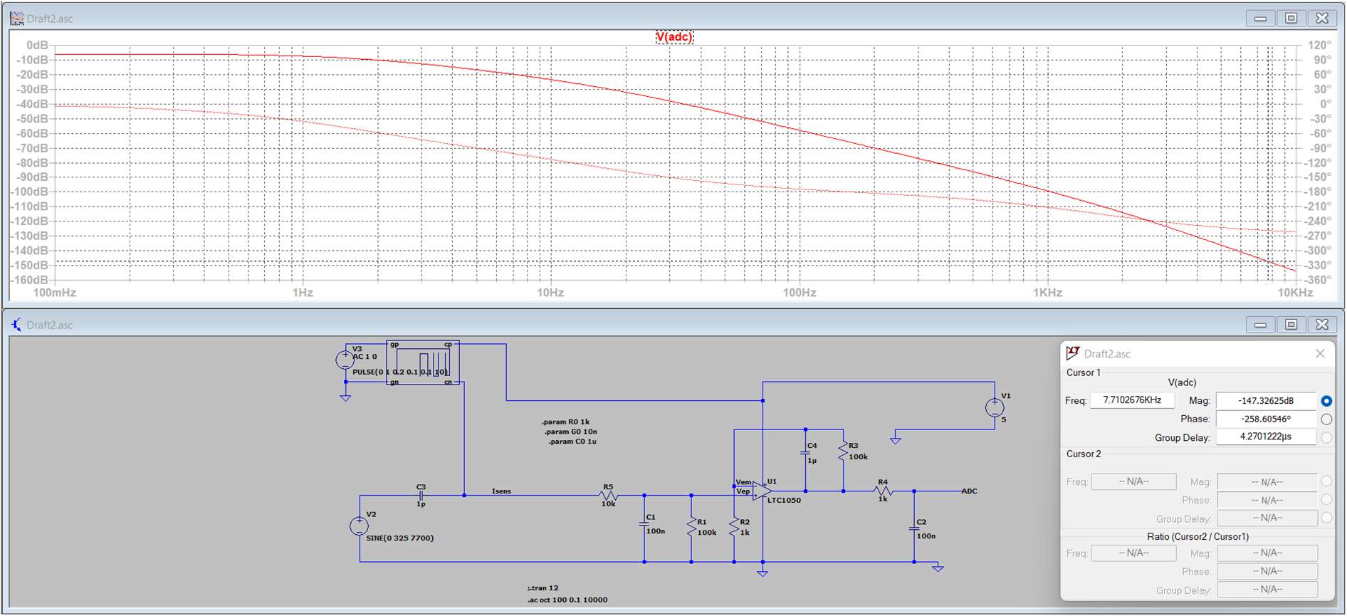
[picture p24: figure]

Diagramme de Bode de la sortie circuit complet pour calcul de l’atténuation d’un bruit à la fréquence limite de repliement.

Ici aussi nous avons réalisé une simulation de courant alternatif (.ac) sur le circuit afin de récupérer le diagramme de Bode de la sortie du circuit. On constate qu’à la fréquence limite de repliement, l’atténuation est de 140dB puisqu’on le diagramme indique -7dB à la fréquence de 0.1Hz et -147dB à 7.7kHz. C’est un indicateur que notre filtrage fonctionne bien, puisque le bruit est complètement atténué en sortie de circuit.

Conclusion :

Ces simulations sur LTSpice nous ont donc permis de vérifier le bon fonctionnement de notre circuit et de comprendre l’utilité de chaque élément présent, en plus de vérifier leur bon fonctionnement. Notre circuit fonctionne correctement, les simulations sont satisfaisantes, il est donc maintenant temps de voir ce qu’il en est dans la réalité.

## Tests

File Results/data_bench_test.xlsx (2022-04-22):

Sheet: Compression
Projet Capteur — PACCARD Luca / LEMAIRE Arthur
 |  |  |  |  |  |  |  |  |  |  |  | Deformation ε | Corresponding diameter (cm)
Measurments #1 |  |  |  |  | Measurments #2 |  |  |  |  | Average Measurments |  | 0 | /
2B #1 |  |  |  |  | 2B #2 |  |  |  |  | 2B |  | 0.003 | 5
Deformation ε | ΔR/R0 (in percent) | R0 | R | ΔR | Deformation ε | ΔR/R0 (in percent) | R0 | R | ΔR | Deformation ε | ΔR/R0 (in percent) | 0.003333333 | 4.5
0.0000 | 0.00 | 210 | 210 | 0 | 0.0000 | 0.00 | 70 | 70 | 0 | 0.0000 | 0.00 | 0.00375 | 4
0.0030 | -14.29 |  | 180 | -30 | 0.0030 | -4.29 |  | 67 | -3 | 0.0030 | -9.29 | 0.004285714 | 3.5
0.0033 | -20.48 |  | 167 | -43 | 0.0033 | -8.57 |  | 64 | -6 | 0.0033 | -14.52 | 0.005 | 3
0.0037 | -15.71 |  | 177 | -33 | 0.0037 | -2.86 |  | 68 | -2 | 0.0037 | -9.29 | 0.006 | 2.5
0.0043 | -19.05 |  | 170 | -40 | 0.0043 | -25.71 |  | 52 | -18 | 0.0043 | -22.38 | 0.0075 | 2
0.0050 | -12.38 |  | 184 | -26 | 0.0050 | -32.86 |  | 47 | -23 | 0.0050 | -22.62
0.0060 | -26.19 |  | 155 | -55 | 0.0060 | -42.86 |  | 40 | -30 | 0.0060 | -34.52
0.0075 | -28.57 |  | 150 | -60 | 0.0075 | -41.43 |  | 41 | -29 | 0.0075 | -35.00
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

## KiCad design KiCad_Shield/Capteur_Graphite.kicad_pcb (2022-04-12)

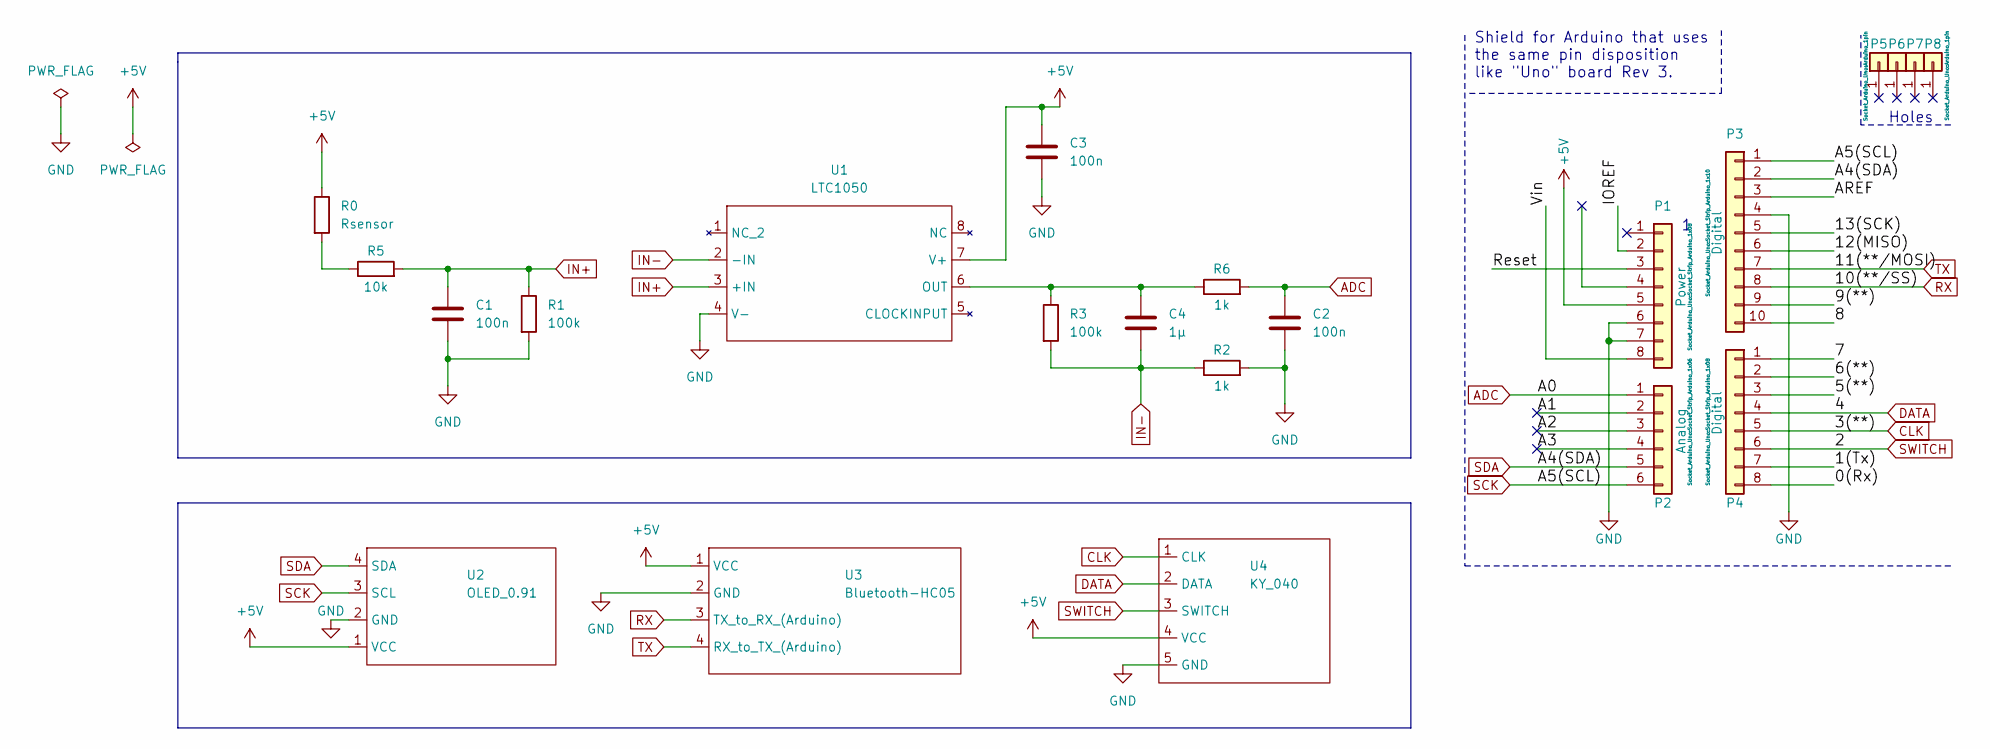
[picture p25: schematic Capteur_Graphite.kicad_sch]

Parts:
C1, C2, C3: 100n; C_Rect_L7.0mm_W2.0mm_P5.00mm
C4: 1µ; C_Rect_L7.0mm_W2.0mm_P5.00mm
P1: Power; Socket_Strip_Arduino_1x08
P2: Analog; Socket_Strip_Arduino_1x06
P3: Digital; Socket_Strip_Arduino_1x10
P4: Digital; Socket_Strip_Arduino_1x08
P5, P6, P7, P8: CONN_01X01; Arduino_1pin
R0: Rsensor; R_Axial_DIN0207_L6.3mm_D2.5mm_P7.62mm_Horizontal
R1, R3: 100k; R_Axial_DIN0207_L6.3mm_D2.5mm_P7.62mm_Horizontal
R2: 1k; R_Axial_DIN0204_L3.6mm_D1.6mm_P7.62mm_Horizontal
R5: 10k; R_Axial_DIN0207_L6.3mm_D2.5mm_P7.62mm_Horizontal
R6: 1k; R_Axial_DIN0204_L3.6mm_D1.6mm_P5.08mm_Horizontal
U1: LTC1050
U2: OLED_0.91; OLED
U3: Bluetooth-HC05; Bluetooth_HC05
U4: KY_040

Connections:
+5V: C3.1, P1.5, R0.1, U1.7 (V+), U2.1 (VCC), U3.1 (VCC), U4.4 (VCC)
/0(Rx): P4.8
/1(Tx): P4.7
/5(**): P4.3
/6(**): P4.2
/7: P4.1
/8: P3.10
/9(**): P3.9
/12(MISO): P3.6
/13(SCK): P3.5
/A1: P2.2
/A2: P2.3
/A3: P2.4
/AREF: P3.3
/IOREF: P1.2
/Reset: P1.3
/Vin: P1.8
ADC: C2.1, P2.1, R6.2
CLK: P4.5, U4.1 (CLK)
DATA: P4.4, U4.2 (DATA)
GND: C1.2, C2.2, C3.2, P1.6, P1.7, P3.4, R1.2, R2.2, U1.4 (V-), U2.2 (GND), U3.2 (GND), U4.5 (GND)
IN+: C1.1, R1.1, R5.2, U1.3 (+IN)
IN-: C4.2, R2.1, R3.2, U1.2 (-IN)
unnamed: C4.1, R3.1, R6.1, U1.6 (OUT)
unnamed: R0.2, R5.1
RX: P3.8, U3.3 (TX_to_RX_(Arduino))
SCK: P2.6, P3.1, U2.3 (SCL)
SDA: P2.5, P3.2, U2.4 (SDA)
SWITCH: P4.6, U4.3 (SWITCH)
TX: P3.7, U3.4 (RX_to_TX_(Arduino))

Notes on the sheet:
Holes
Shield for Arduino that uses the same pin disposition like "Uno" board Rev 3.

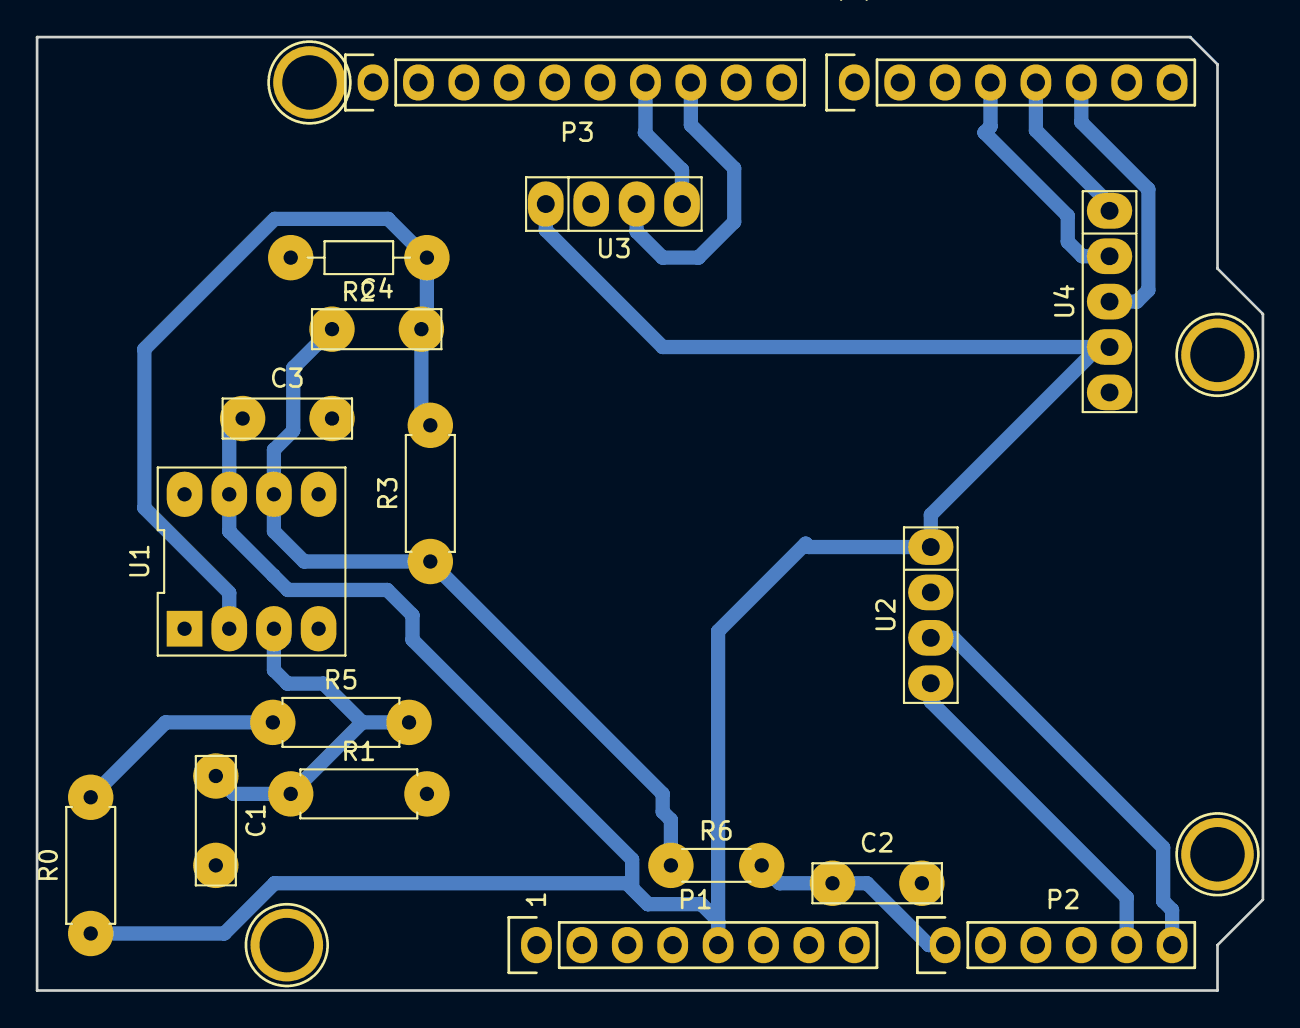
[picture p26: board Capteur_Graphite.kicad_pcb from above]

Board: 2 copper layers, 68.6 x 53.3 mm, 22 parts (0 on the bottom side), 14 nets.

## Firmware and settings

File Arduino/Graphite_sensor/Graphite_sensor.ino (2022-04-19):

#include <Adafruit_SSD1306.h>
#include <SoftwareSerial.h>

#define nombreDePixelsEnLargeur 128         // Taille de l'écran OLED, en pixel, au niveau de sa largeur
#define nombreDePixelsEnHauteur 32          // Taille de l'écran OLED, en pixel, au niveau de sa hauteur
#define brocheResetOLED         -1          // Reset de l'OLED partagé avec l'Arduino (d'où la valeur à -1, et non un numéro de pin)
#define adresseI2CecranOLED     0x3C        // Adresse de "mon" écran OLED sur le bus i2c (généralement égal à 0x3C ou 0x3D)

#define rxPin 7                             // Broche 7 en tant que RX, à raccorder sur RX du HC-05
#define txPin 6                             // Broche 6 en tant que TX, à raccorder sur TX du HC-05

#define pinSW 2
#define pinCLK 3
#define pinDT 4
#define MENU_SIZE 4
  
SoftwareSerial BTserial(rxPin, txPin);      // Définition du software serial

Adafruit_SSD1306 ecranOLED(nombreDePixelsEnLargeur, nombreDePixelsEnHauteur, &Wire, brocheResetOLED);

// ----------------------------
// CAPTEUR --------------------
// ----------------------------
float VADC = 0.0;
float VCC = 5.0;
float R1 = 100000.0;
float R2 = 390.0;
float R3 = 100000.0;
float R5 = 10000.0;
float RS = 0.0;

int analogPin = A0;

// ----------------------------
// ENCODEUR ROTATOIRE ---------
// ----------------------------
// Rotary Encoder Module connections
const int PinSW = 2;   // Rotary Encoder Switch
const int PinDT = 4;    // DATA signal
const int PinCLK = 3;    // CLOCK signal

// Variables to debounce Rotary Encoder
long TimeOfLastDebounce = 0;
int DelayofDebounce = 100;

unsigned long myTime;     // For timer panel

int count1 = 0;           // Count for main_panel
int lastCount1 = 0;

int count2 = 0;           // Count for calibre_panel
int lastCount2 = 0;

long TimeOfLastDebounceSwitch = 0; // Variables to debounce Rotary Encoder Switch button 
int DelayofDebounceSwitch = 500;

bool switch_button = false;
bool prev_switch_button = false;

float calibre = 1.0;

// 'Logo_Grand_Potentiel', 128x64px
const unsigned char myBitmap [] PROGMEM = {
  0xff, 0xff, 0xff, 0xff, 0x00, 0x00, 0x00, 0x00, 0x07, 0xff, 0xff, 0xff, 0xff, 0xff, 0xff, 0xff, 
  0xff, 0xff, 0xff, 0xff, 0x00, 0x00, 0x00, 0x00, 0x07, 0xff, 0xff, 0xff, 0xff, 0xff, 0xff, 0xff, 
  0xff, 0xff, 0xff, 0xff, 0x00, 0x00, 0x00, 0x00, 0x07, 0xff, 0xff, 0xff, 0xff, 0xff, 0xff, 0xff, 
  0xff, 0xff, 0xff, 0xff, 0x00, 0x00, 0x00, 0x00, 0x07, 0xff, 0xff, 0xff, 0xff, 0xff, 0xff, 0xff, 
  0xff, 0xff, 0xff, 0xff, 0x00, 0x00, 0x00, 0x00, 0x07, 0xff, 0xff, 0xff, 0xff, 0xff, 0xff, 0xff, 
  0xff, 0xff, 0xff, 0xff, 0x00, 0x00, 0x00, 0x00, 0x07, 0xff, 0xff, 0xff, 0xff, 0xff, 0xff, 0xff, 
  0xf8, 0xff, 0xff, 0xff, 0x00, 0x00, 0x00, 0x40, 0x07, 0xff, 0xff, 0xff, 0xff, 0xff, 0xff, 0xff, 
  0xc0, 0x1f, 0xff, 0xff, 0x1c, 0x04, 0x00, 0x60, 0x07, 0xff, 0xff, 0xff, 0xff, 0xff, 0xff, 0xff, 
  0x87, 0x0f, 0xff, 0xff, 0x1c, 0x04, 0x00, 0x60, 0x07, 0xff, 0xff, 0xff, 0xff, 0xff, 0xff, 0xff, 
  0x1f, 0x8f, 0xff, 0xff, 0x1e, 0x04, 0x00, 0x60, 0x07, 0xff, 0xff, 0xff, 0xff, 0xff, 0xff, 0xff, 
  0x3f, 0xcf, 0x27, 0x03, 0x13, 0x04, 0x0f, 0xe0, 0x07, 0xff, 0xff, 0xff, 0xff, 0xff, 0xff, 0xff, 
  0x3f, 0xfe, 0x06, 0x01, 0x13, 0x04, 0x19, 0xe0, 0x07, 0xff, 0xff, 0xff, 0xff, 0xff, 0xff, 0xff, 
  0x3e, 0x0e, 0x1e, 0x79, 0x11, 0x84, 0x30, 0x60, 0x07, 0xff, 0xff, 0xff, 0xff, 0xff, 0xff, 0xff, 
  0x3c, 0x0e, 0x3f, 0xf1, 0x10, 0xc4, 0x60, 0x60, 0x07, 0xff, 0xff, 0xff, 0xff, 0xff, 0xff, 0xff, 
  0x3f, 0xc6, 0x3f, 0x01, 0x10, 0xc4, 0x60, 0x60, 0x07, 0xff, 0xff, 0xff, 0xff, 0xff, 0xff, 0xff, 
  0x3f, 0xc6, 0x3c, 0x31, 0x10, 0x6c, 0x60, 0x60, 0x07, 0xff, 0xff, 0xff, 0xff, 0xff, 0xff, 0xff, 
  0x1f, 0xc6, 0x3c, 0x79, 0x10, 0x3c, 0x60, 0x60, 0x07, 0xff, 0xff, 0xff, 0xff, 0xff, 0xff, 0xff, 
  0x0f, 0x86, 0x3c, 0x70, 0x10, 0x3c, 0x30, 0xe0, 0x07, 0xff, 0xff, 0xff, 0xff, 0xff, 0xff, 0xff, 
  0x80, 0x06, 0x3c, 0x00, 0x10, 0x1c, 0x39, 0xe0, 0x07, 0xff, 0xff, 0xff, 0xff, 0xff, 0xff, 0xff, 
  0xe0, 0x6f, 0x7e, 0x01, 0x00, 0x08, 0x0e, 0x00, 0x07, 0xff, 0xff, 0xff, 0xff, 0xff, 0xff, 0xff, 
  0xff, 0xff, 0xff, 0xff, 0x00, 0x00, 0x00, 0x00, 0x07, 0xff, 0xff, 0xff, 0xff, 0xff, 0xff, 0xff, 
  0xff, 0xff, 0xff, 0xff, 0x00, 0x00, 0x00, 0x00, 0x07, 0xff, 0xff, 0xff, 0xff, 0xff, 0xff, 0xff, 
  0xff, 0xff, 0xff, 0xff, 0x00, 0x00, 0x00, 0x00, 0x07, 0xff, 0xff, 0xff, 0xff, 0xff, 0xff, 0xff, 
  0xff, 0xff, 0xff, 0xff, 0x00, 0x00, 0x00, 0x00, 0x07, 0xff, 0xff, 0xff, 0xff, 0xff, 0xff, 0xff, 
  0xff, 0xff, 0xff, 0xff, 0x00, 0x00, 0x00, 0x00, 0x07, 0xff, 0xff, 0xff, 0xff, 0xff, 0xff, 0xff, 
  0xff, 0xff, 0xff, 0xff, 0x00, 0x00, 0x00, 0x00, 0x07, 0xff, 0xff, 0xff, 0xff, 0xff, 0xff, 0xff, 
  0xff, 0xff, 0xff, 0xff, 0x00, 0x00, 0x00, 0x00, 0x07, 0xff, 0xff, 0xff, 0xff, 0xff, 0xff, 0xff, 
  0xff, 0xff, 0xff, 0xff, 0x00, 0x00, 0x00, 0x00, 0x07, 0xff, 0xff, 0xff, 0xff, 0xff, 0xff, 0xff, 
  0xff, 0xff, 0xff, 0xff, 0x00, 0x00, 0x00, 0x00, 0x07, 0xff, 0xff, 0xff, 0xff, 0xff, 0xff, 0xff, 
  0xff, 0xff, 0xff, 0xff, 0x00, 0x00, 0x00, 0x00, 0x07, 0xff, 0xff, 0xff, 0xff, 0xff, 0xff, 0xff, 
  0xff, 0xff, 0xff, 0xff, 0x80, 0x00, 0x00, 0x00, 0x0f, 0xff, 0xff, 0xff, 0xff, 0xff, 0xff, 0xff, 
  0xff, 0xff, 0xff, 0xff, 0xff, 0xff, 0xff, 0xff, 0xff, 0xff, 0xff, 0xff, 0xff, 0xff, 0xff, 0xff, 
  0xff, 0xff, 0xff, 0xff, 0x00, 0x00, 0x00, 0x00, 0x0f, 0xff, 0xff, 0xff, 0xff, 0xff, 0xff, 0xff, 
  0xff, 0xff, 0xff, 0xff, 0x00, 0x00, 0x00, 0x00, 0x07, 0xff, 0xff, 0xff, 0xff, 0xff, 0xff, 0xff, 
  0xff, 0xff, 0xff, 0xff, 0x00, 0x00, 0x00, 0x00, 0x07, 0xff, 0xff, 0xff, 0xff, 0xff, 0xff, 0xff, 
  0xff, 0xff, 0xff, 0xff, 0x00, 0x00, 0x00, 0x00, 0x07, 0xff, 0xff, 0xff, 0xff, 0xff, 0xff, 0xff, 
  0xff, 0xff, 0xff, 0xff, 0x00, 0x00, 0x00, 0x00, 0x07, 0xff, 0xff, 0xff, 0xff, 0xff, 0xff, 0xff, 
  0xff, 0xff, 0xff, 0xff, 0x00, 0x00, 0x00, 0x00, 0x07, 0xff, 0xff, 0xff, 0xff, 0xff, 0xff, 0xff, 
  0xff, 0xff, 0xff, 0xff, 0x00, 0x00, 0x00, 0x00, 0x07, 0xff, 0xff, 0xff, 0xff, 0xff, 0xff, 0xff, 
  0xff, 0xff, 0xff, 0xff, 0x00, 0x00, 0x00, 0x00, 0x07, 0xff, 0xff, 0xff, 0xff, 0xff, 0xff, 0xff, 
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
};

void switched() {  // Changes boolean value if switch button is pushed or not
  if ((millis() - TimeOfLastDebounceSwitch) > DelayofDebounceSwitch) {
    if (switch_button){
      switch_button = false;
    }
    else {
      switch_button = true;
    }
  }
  TimeOfLastDebounceSwitch = millis();
}

void doEncoder() {  // Make the rotation counter to select the menus
  
  if ((millis() - TimeOfLastDebounce) > DelayofDebounce) {  // debouncing
    if (digitalRead(pinDT) == digitalRead(pinCLK)) {
      if (!switch_button){
        count1--;
        if (lastCount1 == 0) {
            count1 = 3;
        }
      }
      else if (switch_button){
        count2--;
      if (lastCount2 == 0) {
          count2 = 2;
        }
      }
    }
    else if (digitalRead(pinDT) != digitalRead(pinCLK)) {
      if (!switch_button) {
        count1++;
        if (lastCount1 == 3) {
            count1 = 0;
        }
      }
      else if (switch_button){
        count2++;
        if (lastCount2 == 2) {
          count2 = 0;
        }
      }
    }
  }
  lastCount1 = count1;
  lastCount2 = count2;
  TimeOfLastDebounce = millis();  // Set variable to current millis() timer
  Serial.println(count1);
}


void main_panel() {  // displays everything on the OLED
  ecranOLED.clearDisplay();
  ecranOLED.setCursor(0,1);
  
  const char *options[4] = {
    " Resistance & Voltage",
    " Calibre",
    " Timer",
    " GP"
  };

  if (!switch_button) {     // main menu
    for (int i = 0; i < 5; i++) {
      if (i == count1) {
        ecranOLED.setTextColor(SSD1306_BLACK, SSD1306_WHITE);
        ecranOLED.println(options[i]);
      } else if (i != count1) {  
        ecranOLED.setTextColor(SSD1306_WHITE);
        ecranOLED.println(options[i]);
      }
    }
  }
  else if (switch_button) {   // sub-menus
    ecranOLED.drawRect(0, 0, 128,32, WHITE);
    
    if (count1 == 0) {        // Resistance & voltage sub-menu
      ecranOLED.setCursor(0, 2);
      ecranOLED.println(" Resistance :");
      ecranOLED.print(" ");
      ecranOLED.print(RS);
      if (count2 == 0) {
        calibre = 1;
        ecranOLED.println(" ohm");
      }
      else if (count2 == 1) {
        calibre = 0.001;
        ecranOLED.println(" kohm");
      }
      else if (count2 == 2) {
        calibre = 0.000001;
        ecranOLED.println(" Mohm");
      }
      ecranOLED.setCursor(0, 21);
      ecranOLED.print(" Voltage :  ");
      ecranOLED.setTextSize(1);
      ecranOLED.print(VADC);
      ecranOLED.print(" V");
    }
    
    else if (count1 == 1) {   // calibre sub-menu
      calibre_panel();
    }
    
    else if (count1 == 2) {   // timer sub-menu
      ecranOLED.setCursor(0, 2);
      ecranOLED.println(" Time since program");
      ecranOLED.println(" started :");
      ecranOLED.setCursor(30, 21);
      ecranOLED.print(myTime);
      ecranOLED.println(" seconds");
    }
    
    else if (count1 == 3) {   // image sub-menu
      ecranOLED.clearDisplay();
      ecranOLED.drawBitmap(0, 0, myBitmap, 128, 64, WHITE); // display.drawBitmap(x position, y position, bitmap data, bitmap width, bitmap height, color)
    }
  }

  
  ecranOLED.display();
}

void calibre_panel() {    // allows to select a calibre for resistance value
  ecranOLED.setCursor(0, 4);
  const char *options_calibre[3] = {
    "    ohm",
    "  k ohm",
    "  M ohm"
  };
  for (int i = 0; i < 3; i++) {
    if (i == count2) {
      ecranOLED.setTextColor(SSD1306_BLACK, SSD1306_WHITE);
      ecranOLED.println(options_calibre[i]);
    } else if (i != count2) {  
      ecranOLED.setTextColor(SSD1306_WHITE);
      ecranOLED.println(options_calibre[i]);
    }
  }
  ecranOLED.setCursor(100, 23);
  ecranOLED.print("HBKT");
}


// --------------------------------------------------------------------------------------------
// SETUP --------------------------------------------------------------------------------------
// --------------------------------------------------------------------------------------------

void setup() {
  Serial.begin(9600);
  BTserial.begin(9600);
  
  pinMode(A0, INPUT); // pin pour entrée analogique, mesure de tension VADC

  ecranOLED.begin(SSD1306_SWITCHCAPVCC, adresseI2CecranOLED);
  ecranOLED.clearDisplay();                 // Effaçage de l'intégralité du buffer
  ecranOLED.setTextSize(1);                 // Taille des caractères 
  ecranOLED.setCursor(0, 0);                // Déplacement du curseur en postion (0,0)
  ecranOLED.setTextColor(SSD1306_WHITE);


  pinMode(rxPin, INPUT);        // pin for bluetooth module
  pinMode(txPin, OUTPUT);       // pin for bluetooth module

  pinMode(pinCLK, INPUT);
  pinMode(pinDT, INPUT);
  pinMode(pinSW, INPUT_PULLUP); // Set the Switch pin to use Arduino PULLUP resistors

  attachInterrupt(digitalPinToInterrupt(pinCLK), doEncoder, CHANGE);    // attach interrupt for rotation movement
  attachInterrupt(digitalPinToInterrupt(pinSW), switched, CHANGE);      // attach interrupt for switch button
}



// --------------------------------------------------------------------------------------------
// LOOP ---------------------------------------------------------------------------------------
// --------------------------------------------------------------------------------------------

void loop() {
  VADC = analogRead(analogPin)*0.004882814;     // sensor voltage read by the arduino 
  
  RS = ( ((1 + R3/R2)*R1*(VCC/VADC)) - R1 - R5) * calibre;  // sensor resistance
  
  main_panel();
  
  myTime = millis() / 1000;            
  
  prev_switch_button = switch_button;
  
  byte VADC1 = map(analogRead(analogPin), 0, 1024, 0, 255); //Encodage de la tension VADC sur un byte
  BTserial.write(VADC1); // Envoie de la donnée de tension sur un byte
  delay(100);
}

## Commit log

2022-04-12 Add of PCB
2022-04-12 add of PCB photos
2022-04-12 Shield KiCad
    [Capteur_Graphite.kicad_pcb, Capteur_Graphite.kicad_sch]
2022-04-14 Arduino code
2022-04-15 Add bench test results
    [data_bench_test.xlsx]
2022-04-19 Final bench test results
    [data_bench_test.xlsx]
2022-04-19 Minor graph title change
    [data_bench_test.xlsx]
2022-04-20 update nbre de chiffres significatifs
    [data_bench_test.xlsx]
2022-04-22 Ajout des data du flex sensor
    [data_bench_test.xlsx]
